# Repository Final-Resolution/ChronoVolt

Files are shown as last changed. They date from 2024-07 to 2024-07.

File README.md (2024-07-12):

# ChronoVolt

使用8-MD-06INKM制作的VFD时钟，基于ESP32-WROOM

## 项目概述

项目概述是关于项目的一段简短描述，解释该项目是什么以及它的目标和用途。

## 功能特点

列出项目的主要功能和特点，突出该项目的独特之处。

- 特点1：说明特点1的功能和优势。
- 特点2：说明特点2的功能和优势。
- 特点3：说明特点3的功能和优势。

## 安装和使用

提供项目的安装和使用指南，以帮助其他用户快速上手和开始使用该项目。

1. 安装步骤1。
2. 安装步骤2。
3. 使用示例代码或配置文件。

## 硬件设计

如果项目涉及硬件设计，可以提供有关硬件设计的详细信息。

- 原理图：放置原理图文件的链接或说明。
- 电路板布局：放置电路板布局文件的链接或说明。
- 元件清单：列出所使用的主要元件和器件。

## 软件/固件

如果项目涉及软件或固件开发，可以提供有关软件/固件的详细信息。

- 代码库：放置代码库的链接或说明。
- 依赖项：列出所需的主要软件或库的依赖项。

## 贡献

欢迎其他开发者和用户为该项目做出贡献。在贡献部分提供以下信息：

- 贡献方式：说明如何参与该项目的贡献，例如提交问题、提出建议或提交代码。 
- 贡献指南：提供贡献者应遵循的指南和行为准则。
- 开发环境设置：提供如何设置开发环境的说明。

## 许可证

在这个部分指定项目的许可证类型和版权信息。

## 联系方式

提供与项目相关的联系方式，例如邮件地址、社交媒体链接等。

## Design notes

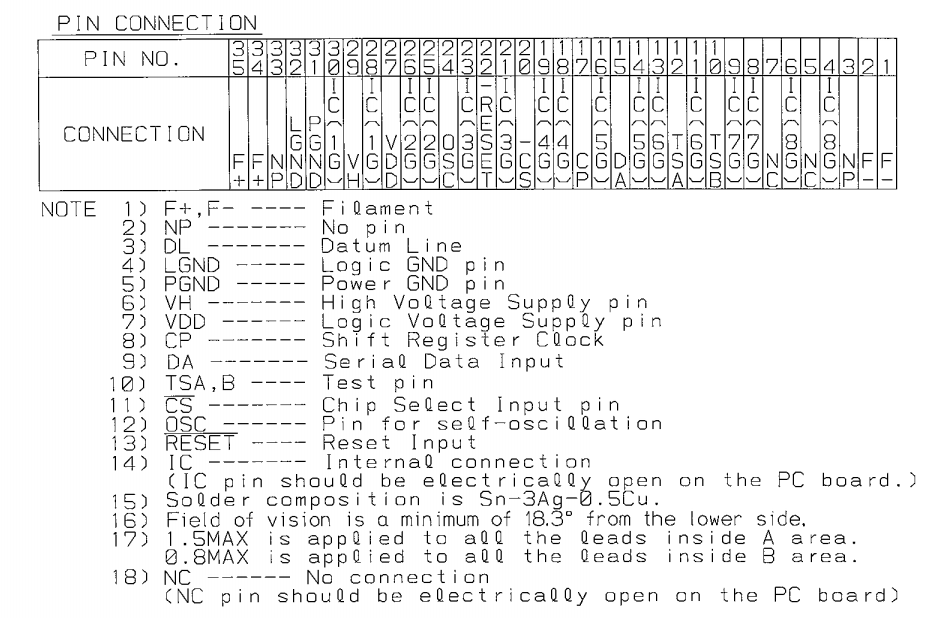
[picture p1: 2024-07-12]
1.Hardware/ChronoVolt_Control_Rev0.3/datasheets/8-MD-06INKM模块/8-MD-06INKM_PINOUT.png

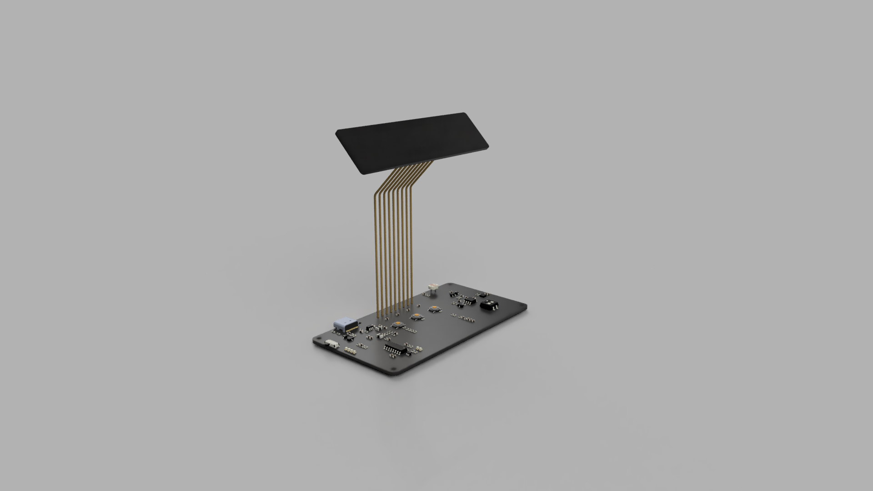
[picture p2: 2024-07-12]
4.Images/ChronoVolt_3D.PNG

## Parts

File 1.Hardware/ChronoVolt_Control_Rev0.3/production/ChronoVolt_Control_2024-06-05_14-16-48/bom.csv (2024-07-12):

Designator | Footprint | Quantity | Value | LCSC Part #
BT1 | CONN-SMD_ZH1.5-2P-WT | 1 | Battery
BT2 | BS-1220-2 | 1 | Battery_Cell
C1, C12, C2, C20, C21, C24, C25, C26, C27, C28, C29, C3, C30, C4, C9 | 0603 | 15 | 100nF
C10 | 0603 | 1 | 1uF
C11 | 0603 | 1 | 22uF
C13, C14 | 0603 | 2 | 9pF
C15, C32, C33 | 0603 | 3 | 0.1μF
C16, C17, C18, C19 | 0603 | 4 | 10uF
C5, C7, C8 | 0603 | 3 | 22μF
C6 | 0603 | 1 | 22pF
D10, D11, D12, D13 | LED-SMD_4P-L2.0-W1.8_CY-0807 | 4 | WS2812B
D14 | D_SOD-323 | 1 | 1N4148
D15, D16 | D_SOD-323 | 2 | 1N4148WS
D3 | 0603 | 1 | TX_LED
D4 | 0603 | 1 | RX_LED
D5 | D_SOD-323 | 1 | 1N5819
D6 | 0603 | 1 | 25%
D7 | 0603 | 1 | 50%
D8 | 0603 | 1 | 75%
D9 | 0603 | 1 | 100%
F1 | 0805 | 1 | Fuse
H1, H2, H3, H4 | MountingHole_2.5mm_Pad_Via | 4 | MountingHole_Pad
J1 | USB_C_Receptacle_Palconn_UTC16-G | 1 | USB_C_Receptacle_USB2.0
J2 | Con_Pin_1x09_3mm | 1 | Conn_01x09_Pin
L1 | 1008 | 1 | 2.2μH
L2 | 1008 | 1 | 1uH
LS1 | BUZ-SMD_4P-L8.5-W8.5-TL | 1 | Buzzer_MLT-8530_Passive
Q1 | TSOT-23 | 1 | CJ2301
Q3 | SOT-23 | 1 | AO3400A
R1, R2 | 0603 | 2 | 5.1K
R10, R11, R14, R15, R31, R36, R37, R38, R39, R40, R41, R7 | 0603 | 12 | 10K
R12, R13, R20, R21 | 0603 | 4 | 4.7K
R16 | 0603 | 1 | 4K7
R19, R24, R27, R32, R42 | 0603 | 5 | 0R
R23 | 0603 | 1 | 0.5R
R25, R26 | 0603 | 2 | 470K
R3, R33, R4, R5, R6 | 0603 | 5 | 470R
R30 | R_LDR_5.1x4.3mm_P3.4mm_Vertical | 1 | LDR_GL5528
R34 | 0603 | 1 | 100R
R35 | 0603 | 1 | 2K
R8 | 0603 | 1 | 100K
R9 | 0603 | 1 | 22K
SW1 | SW_SPDT_PCM12 | 1 | SW_Push_SPDT
SW2 | Panasonic_EVQPUL_EVQPUC | 1 | EN_KEY
SW3 | Panasonic_EVQPUL_EVQPUC | 1 | BOOT_KEY
SW5 | SW_SPST_TL3342 | 1 | UP_KEY
SW6 | SW_DIP_SPSTx02_Slide_6.7x6.64mm_W8.61mm_P2.54mm_LowProfile | 1 | MODE_SWITCH
SW7 | SW_SPST_TL3342 | 1 | ENTER_KEY
SW8 | SW_SPST_TL3342 | 1 | DOWN_KEY
TP1, TP3 | TestPoint_Pad_D1.0mm | 2 | TP_GND
TP2 | TestPoint_Pad_D1.0mm | 1 | TP_3V3
TP4 | TestPoint_Pad_D1.0mm | 1 | TP_VBUS
TP5 | TestPoint_Pad_D1.0mm | 1 | TP_+BATT
TP6 | TestPoint_Pad_D1.0mm | 1 | TP_BAT
TP7 | TestPoint_Pad_D1.0mm | 1 | TP_+5V
TP8 | TestPoint_Pad_D1.0mm | 1 | TP_+3v3
U1 | SOT-363_SC-70-6 | 1 | DDC114TU-7-F
U2 | SOIC-16_3.9x9.9mm_P1.27mm | 1 | CH340C
U3 | SOT-23-5 | 1 | SY8089AAAC
U4 | ESP32-WROOM-32D | 1 | ESP32-WROOM-32D
U5 | SOIC-8_3.9x4.9mm_P1.27mm | 1 | BM8563EMA
U6 | SOIC-8-1EP_3.9x4.9mm_P1.27mm_EP2.29x3mm_ThermalVias | 1 | IP5306
U8 | Sensirion_DFN-8-1EP_2.5x2.5mm_P0.5mm_EP1.1x1.7mm | 1 | SHT31-DIS
Y1 | Crystal_SMD_3215-2Pin_3.2x1.5mm | 1 | 32.768KHz

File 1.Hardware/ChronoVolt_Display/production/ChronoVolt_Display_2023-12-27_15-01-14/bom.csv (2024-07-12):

Designator | Footprint | Quantity | Value | LCSC Part #
C1 | 0603 | 1 | 0.1uF
C10, C3, C7, C9 | 0603 | 4 | 22μF
C2 | 0603 | 1 | 47uF
C4 | 0603 | 1 | 22pF/50V
C5 | 0603 | 1 | 0.1μF/50V
C6 | 0603 | 1 | 4.7μF/50V
C8 | 0603 | 1 | 22pF
D1, D2 | D_SOD-323 | 2 | 1N5819WS
J1 | Con_Pin_1x09_3mm | 1 | Conn_01x09_Pin
L1 | 1008 | 1 | 10uH
L2 | 1008 | 1 | 2.2μH
Q1 | TSOT-23 | 1 | CJ2301
R1, R2 | 0603 | 2 | 3R
R10, R13, R5, R6, R7 | 0603 | 5 | 10K
R11 | 0603 | 1 | 100K
R12 | 0603 | 1 | 22K
R3 | 0603 | 1 | 39K
R4 | 0603 | 1 | 180R
R8 | 0603 | 1 | 300K
R9 | 0603 | 1 | 16K
TP1 | TestPoint_Pad_D1.0mm | 1 | TP_GND
TP2 | TestPoint_Pad_D1.0mm | 1 | TP_+5V
TP3 | TestPoint_Pad_D1.0mm | 1 | TP_+3v3
TP4 | TestPoint_Pad_D1.0mm | 1 | TP_+24V
U1 | TSOT-23-5 | 1 | SGM6601YTN5G/TR
U2 | SOT-23-5 | 1 | SY8089AAAC
VFD1 | FUTABA_8-MD-06INKM | 1 | Futaba_8-MD-06INKM

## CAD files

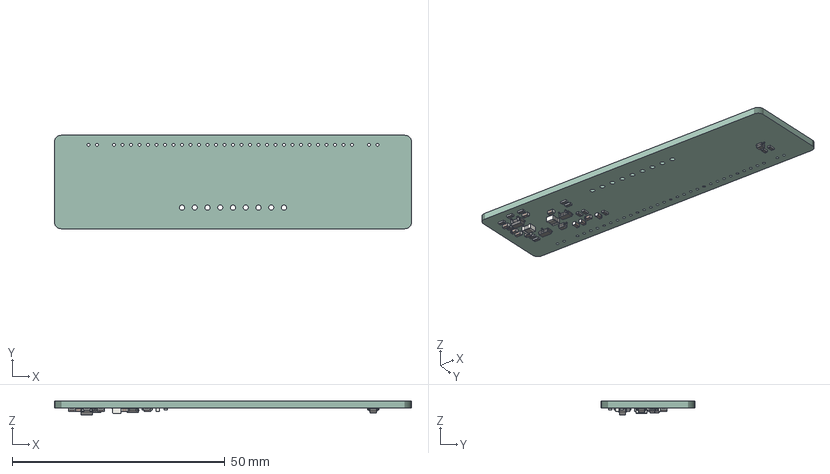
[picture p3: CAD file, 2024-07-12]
1.Hardware/ChronoVolt_Display/ChronoVolt_Display.step
84.0 x 22.0 x 3.20 mm
R_0603_1608Metric x 13
C_0603_1608Metric x 10
SOT_23_5
D_SOD_323 x 2
TSOT_23_5
L_1008_2520Metric x 2
TSOT_23
ChronoVolt_Display PCB

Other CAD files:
1.Hardware/ChronoVolt_Control_Rev0.3/datasheets/8-MD-06INKM模块/code/代码示例工程/test/output/main.obj
1.Hardware/ChronoVolt_Control_Rev0.3/datasheets/8-MD-06INKM模块/code/代码示例工程/test/output/common.obj
1.Hardware/ChronoVolt_Control_Rev0.3/datasheets/8-MD-06INKM模块/code/代码示例工程/test/output/clock.obj
1.Hardware/ChronoVolt_Control_Rev0.3/datasheets/8-MD-06INKM模块/code/代码示例工程/test/output/initial.obj
1.Hardware/ChronoVolt_Control_Rev0.3/datasheets/8-MD-06INKM模块/code/代码示例工程/test/output/sfr_macro.obj
1.Hardware/ChronoVolt_Control_Rev0.3/datasheets/8-MD-06INKM模块/code/代码示例工程/test/output/vfd_8md06inkm.obj
1.Hardware/ChronoVolt_Control_Rev0.3/datasheets/8-MD-06INKM模块/code/代码示例工程/test/output/pt6312.obj
1.Hardware/ChronoVolt_Control_Rev0.3/datasheets/8-MD-06INKM模块/code/代码示例工程/test/output/font_seg13.obj
1.Hardware/ChronoVolt_Control_Rev0.3/datasheets/8-MD-06INKM模块/code/代码示例工程/test/output/STARTUP.obj

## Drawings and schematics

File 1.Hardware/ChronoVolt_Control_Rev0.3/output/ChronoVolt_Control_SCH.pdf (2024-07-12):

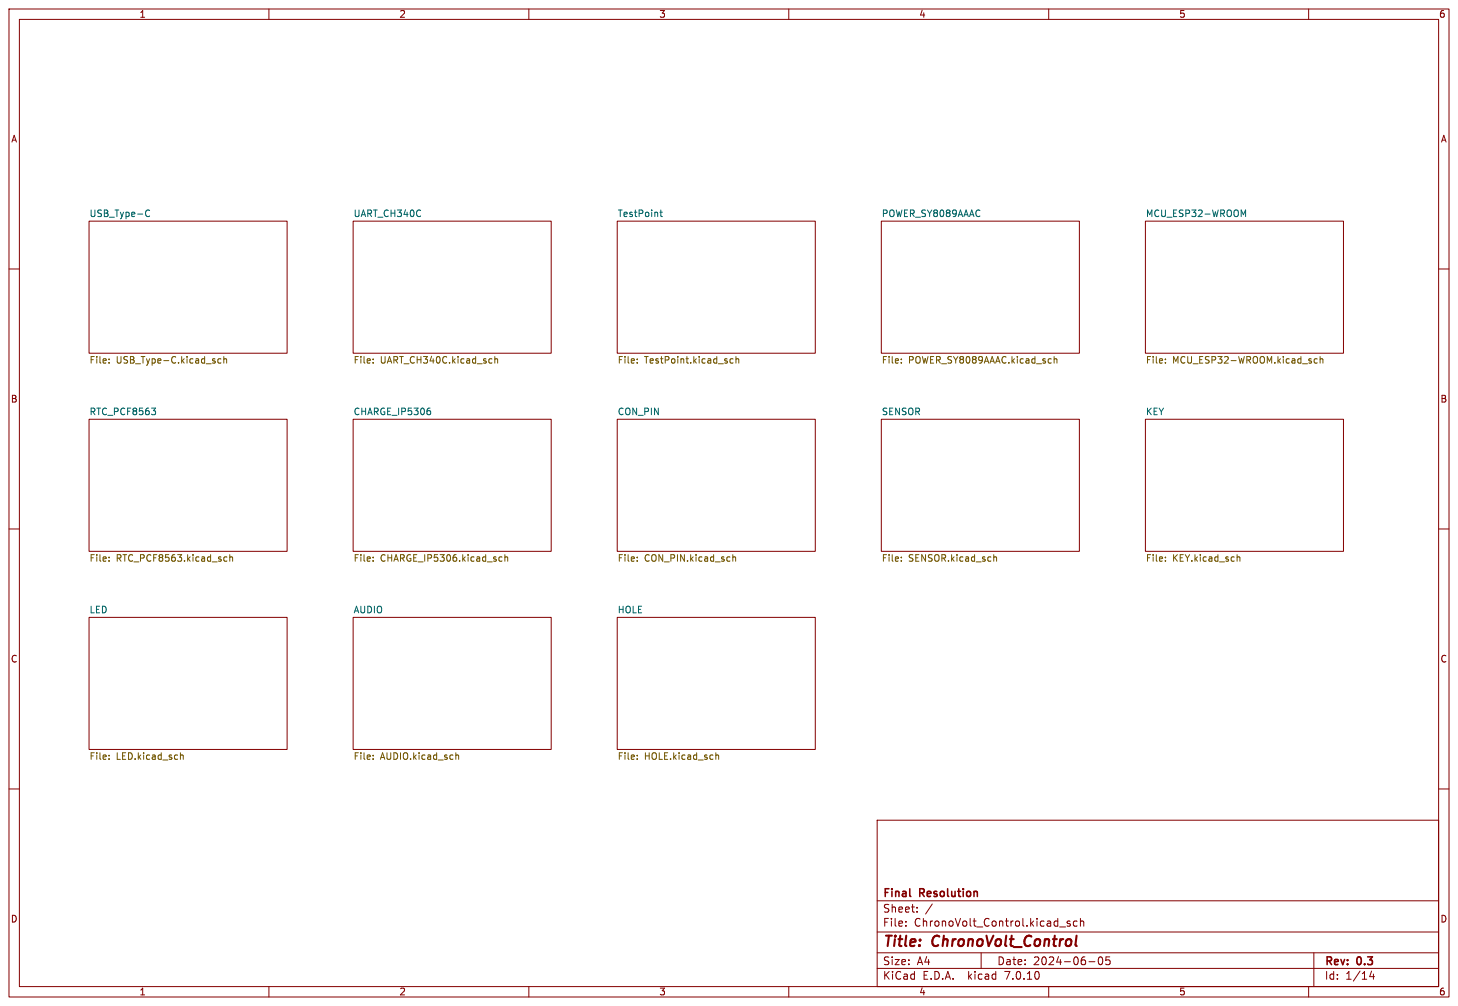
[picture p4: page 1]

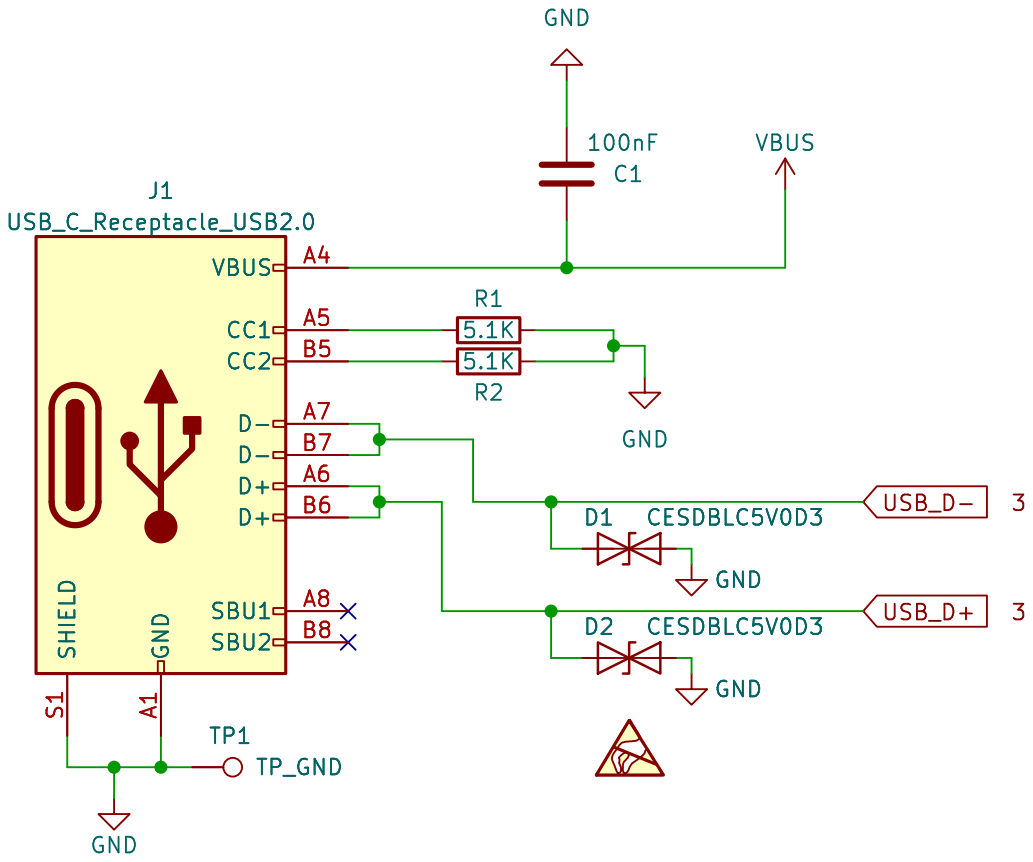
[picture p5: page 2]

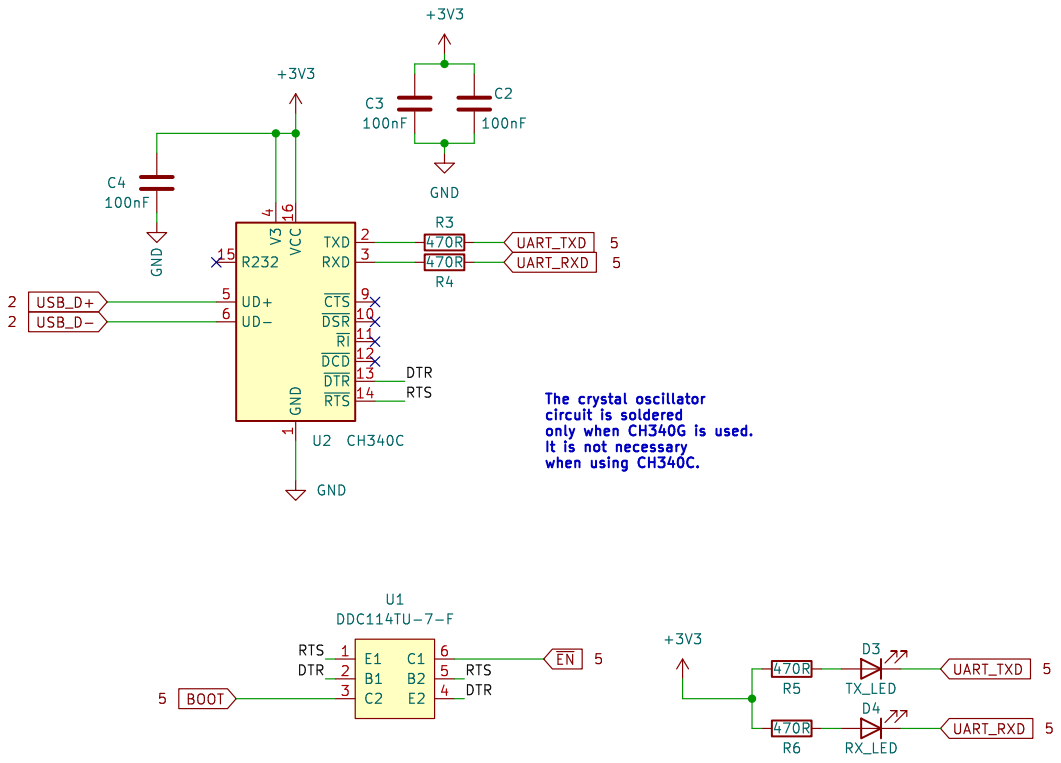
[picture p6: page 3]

1 ~{DSR} 10 ~{RI} 11 ~{DCD} 12 ~{DTR} 13 ~{RTS} 14 R232 15 VCC 16 TXD 2 RXD 3 V3

The crystal oscillator circuit is soldered

only when CH340G is used.
It is not necessary when using CH340C.

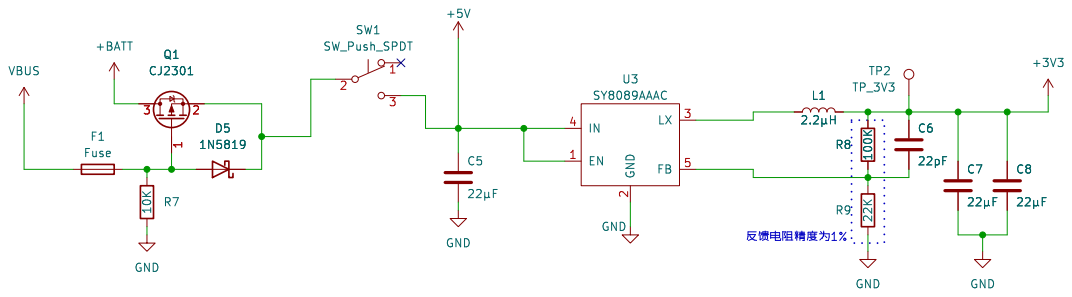
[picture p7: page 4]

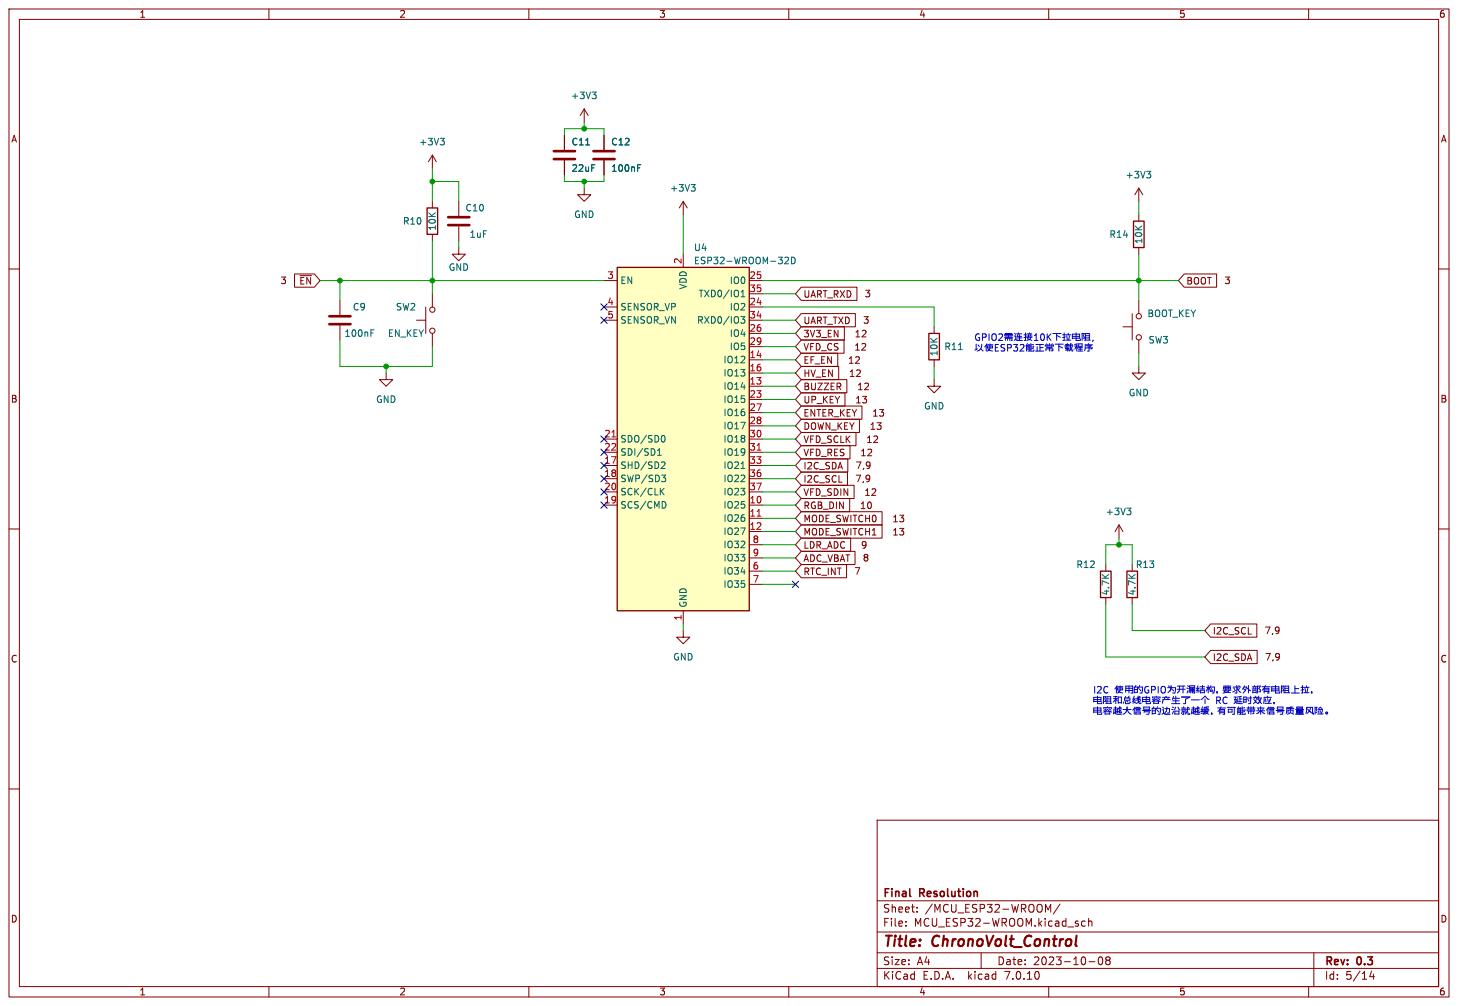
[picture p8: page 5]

2 SCK/CLK 20 SDO/SD0 21 SDI/SD1 22

I2C þÿO•u(v„GPION:_o~Óg„ÿ‰•lBY•èg u5–;N
þÿu5–;TŒ`;~¿u5[¹N§uN†NN*RC þÿ^öeöeH^”ÿ
þÿu5[¹•ŠY'OáS÷v„•¹l¿\1•Š•ÿg Sï€ý^&geOáS÷•(‘Ï˜Î–i0-

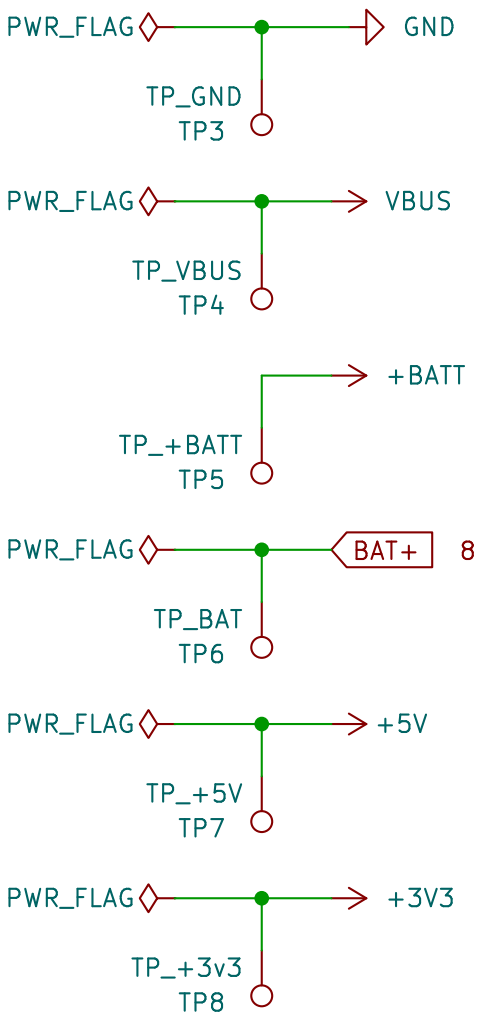
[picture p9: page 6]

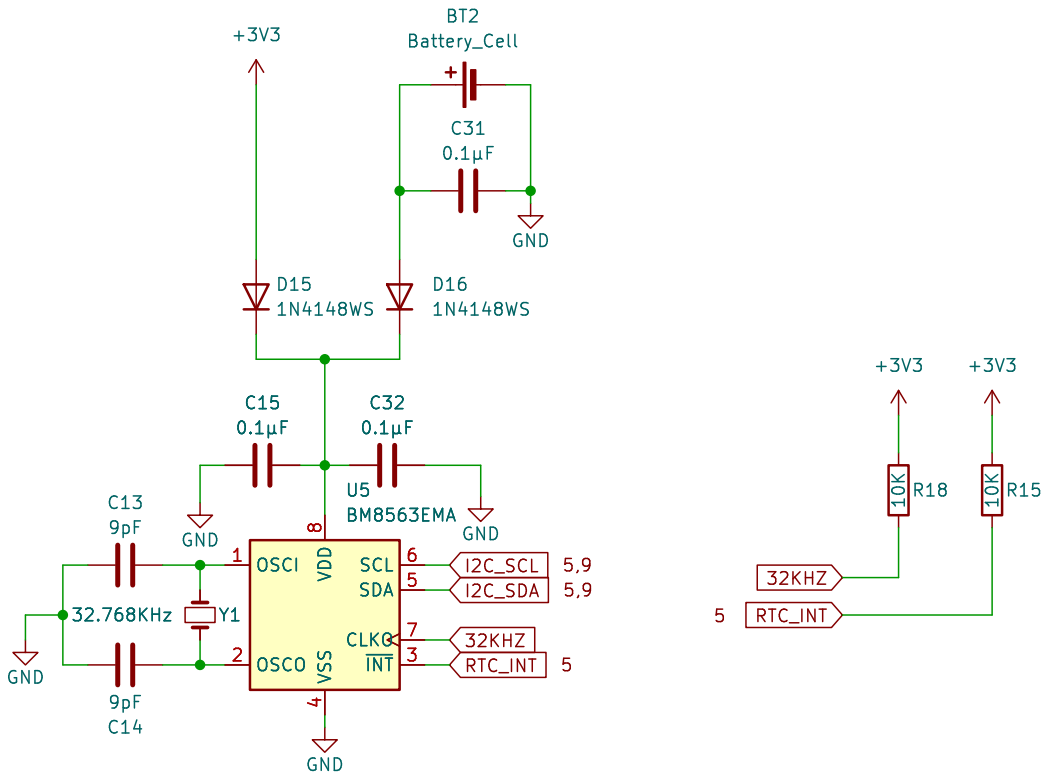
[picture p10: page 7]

4 SDA 5 SCL 6 CLKO 7 VDD

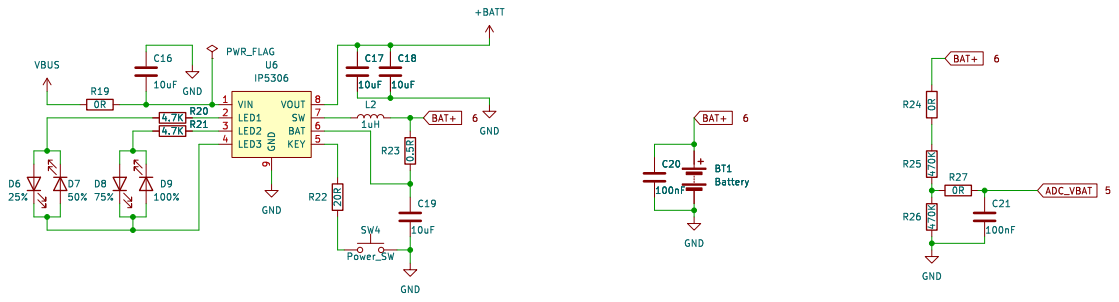
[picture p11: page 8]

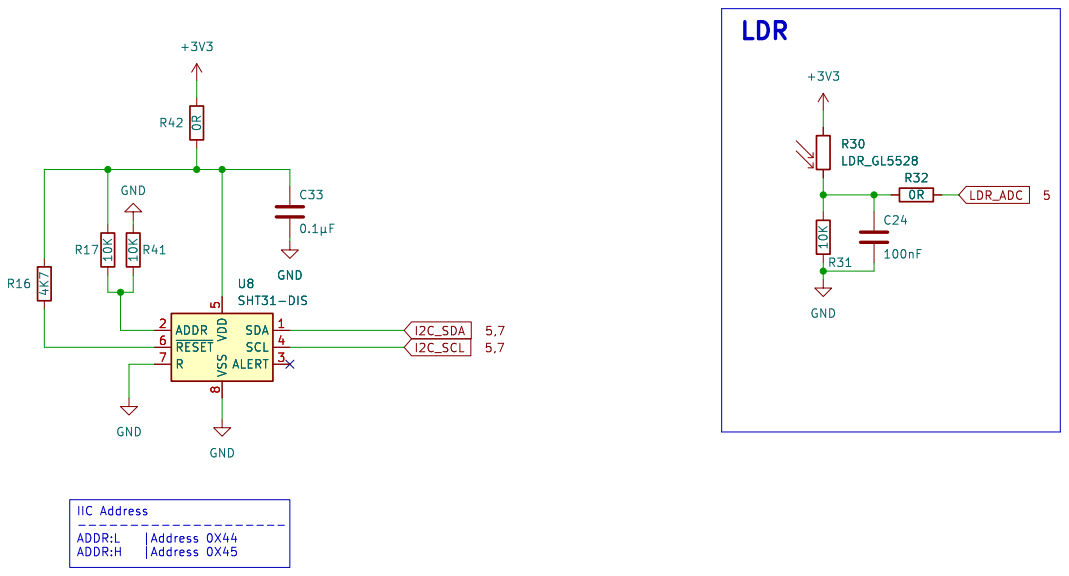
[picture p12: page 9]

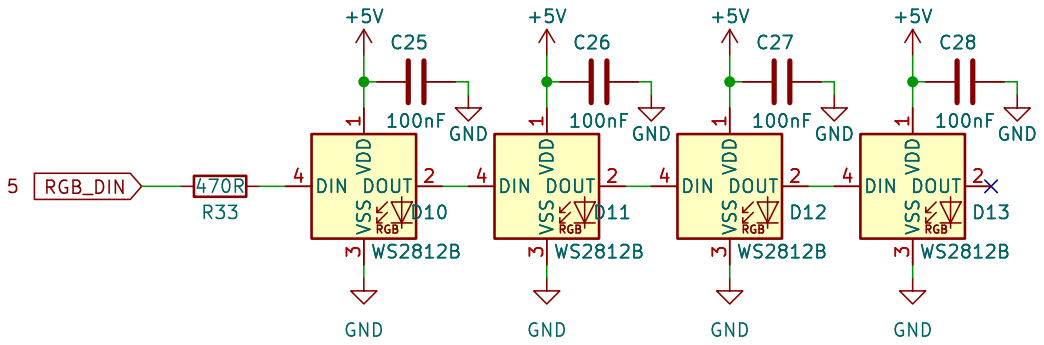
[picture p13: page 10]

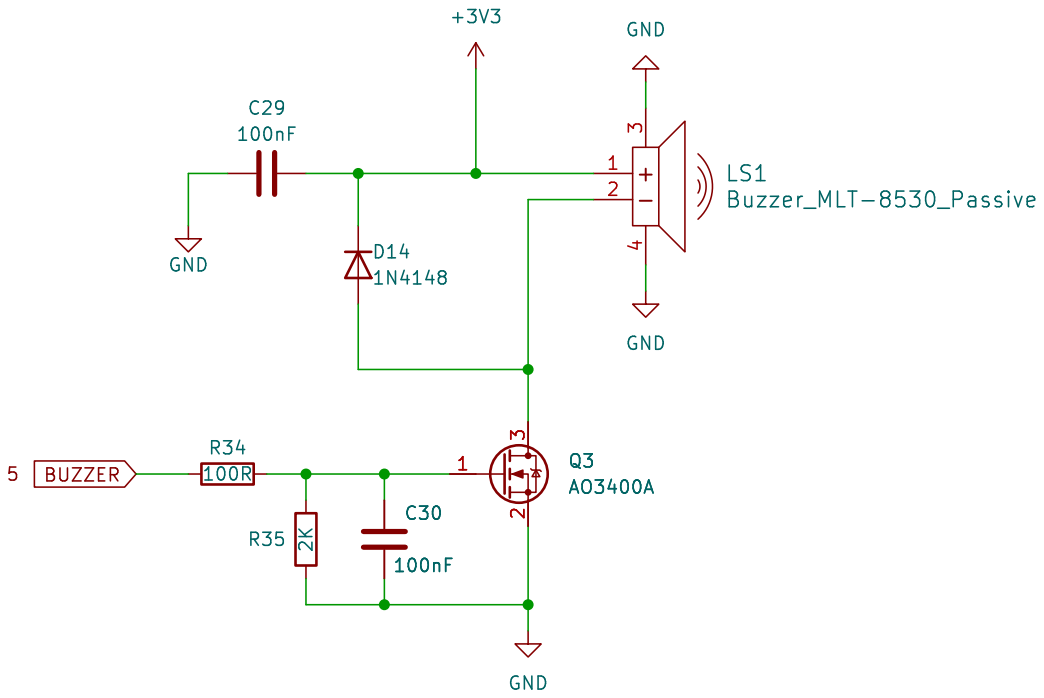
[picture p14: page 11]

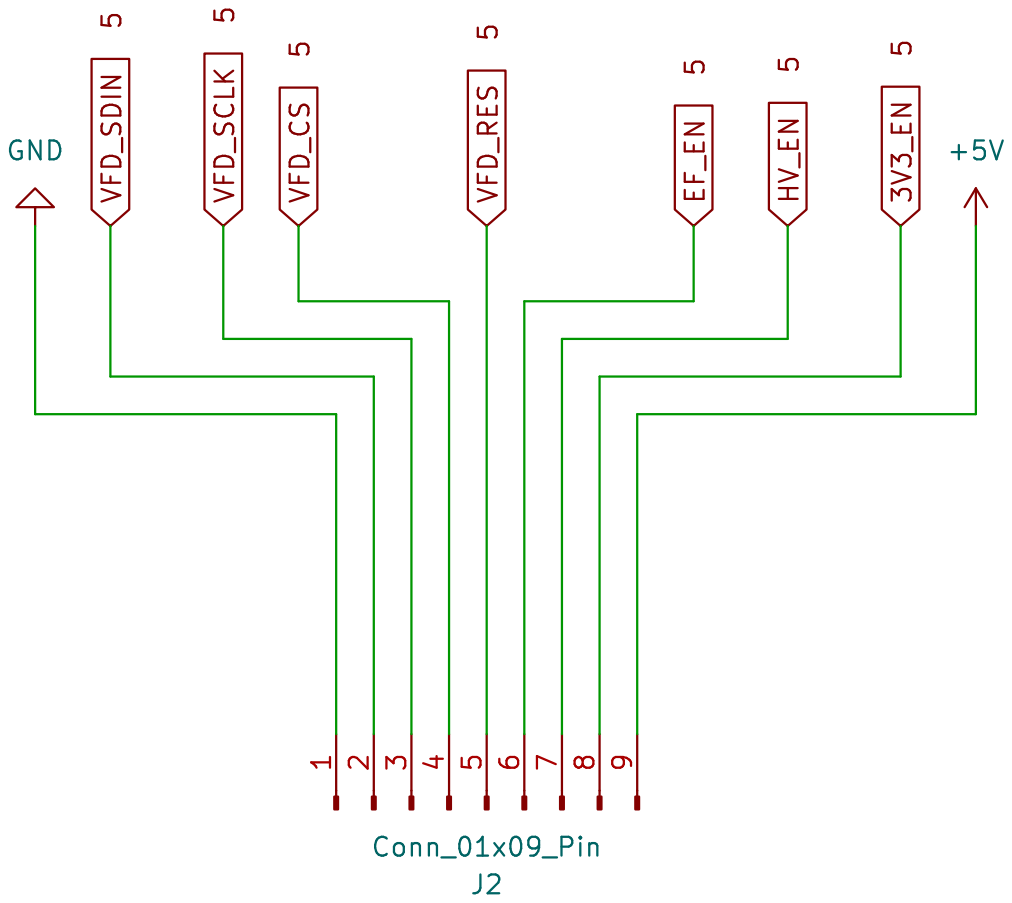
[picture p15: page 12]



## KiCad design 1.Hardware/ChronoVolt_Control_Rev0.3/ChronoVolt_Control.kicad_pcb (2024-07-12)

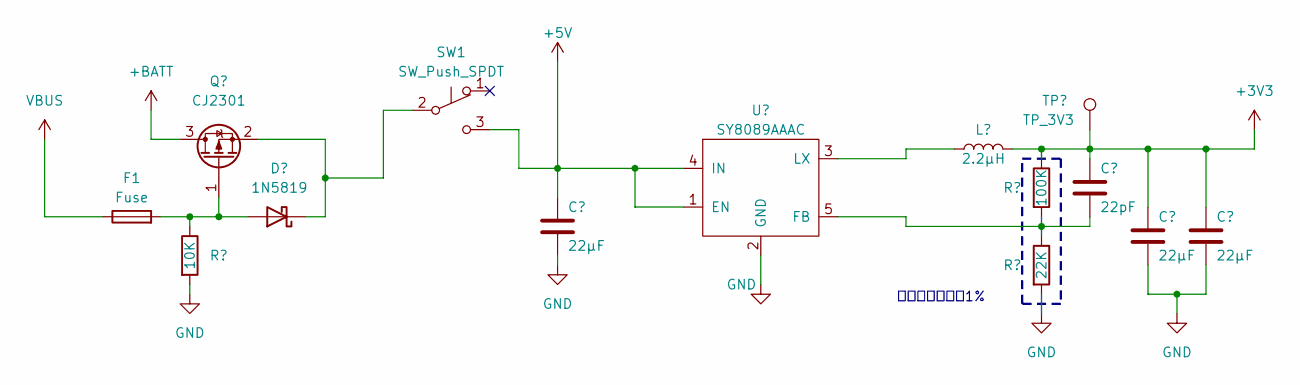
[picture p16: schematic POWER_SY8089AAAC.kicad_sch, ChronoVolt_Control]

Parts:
C5, C7, C8: 22μF; C_0603_1608Metric
C6: 22pF; C_0603_1608Metric
D5: 1N5819; D_SOD-323
F1: Fuse; Fuse_0805_2012Metric
L1: 2.2μH; L_1008_2520Metric
Q1: CJ2301; TSOT-23
R7: 10K; R_0603_1608Metric
R8: 100K; R_0603_1608Metric
R9: 22K; R_0603_1608Metric
SW1: SW_Push_SPDT; SW_SPDT_PCM12
TP2: TP_3V3; TestPoint_Pad_D1.0mm
U3: SY8089AAAC; SOT-23-5

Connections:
+3V3: C6.1, C7.1, C8.1, L1.2, R8.1, TP2.1; also elsewhere on the board
+5V: C5.1, SW1.3 (C), U3.1 (EN), U3.4 (IN); also elsewhere on the board
+BATT: Q1.3 (D); also elsewhere on the board
GND: C5.2, C7.2, C8.2, R7.2, R9.2, U3.2 (GND); also elsewhere on the board
unnamed: D5.2 (A), F1.2, Q1.1 (G), R7.1
unnamed: D5.1 (K), Q1.2 (S), SW1.2 (B)
unnamed: C6.2, R8.2, R9.1, U3.5 (FB)
unnamed: L1.1, U3.3 (LX)
VBUS: F1.1; also elsewhere on the board

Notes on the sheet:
反馈电阻精度为1%

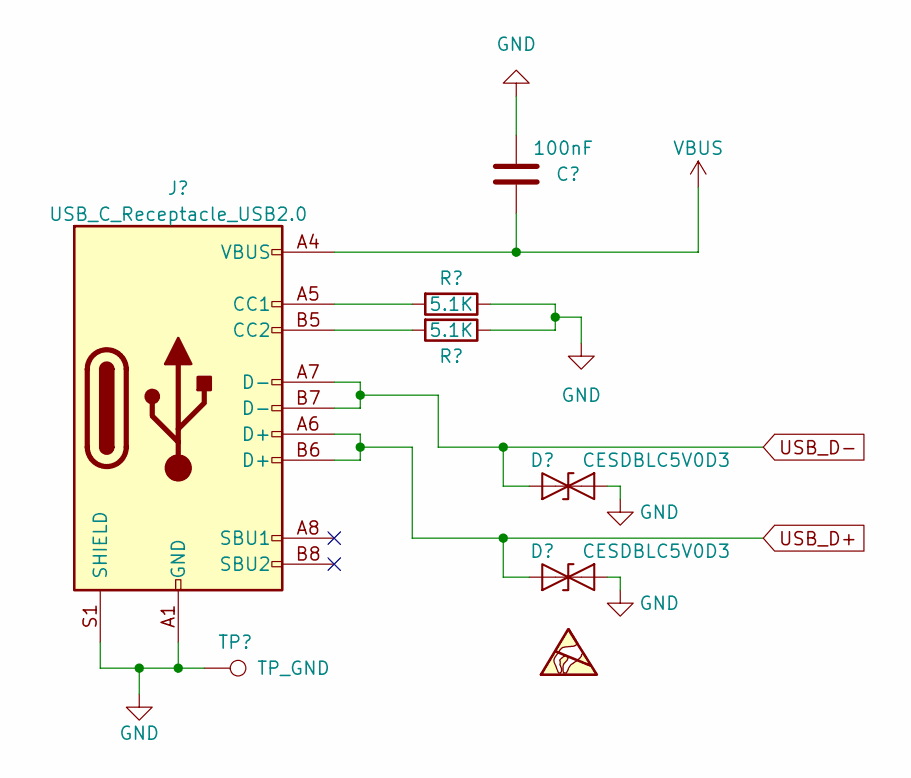
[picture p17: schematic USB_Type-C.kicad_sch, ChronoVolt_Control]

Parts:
C1: 100nF; C_0603_1608Metric
D1, D2: CESDBLC5V0D3; D_SOD-923
J1: USB_C_Receptacle_USB2.0; USB_C_Receptacle_Palconn_UTC16-G
R1, R2: 5.1K; R_0603_1608Metric
TP1: TP_GND; TestPoint_Pad_D1.0mm

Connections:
GND: C1.2, D1.1 (A1), D2.1 (A1), J1.A1 (GND), J1.A12 (GND), J1.B1 (GND), J1.B12 (GND), J1.S1 (SHIELD), R1.1, R2.1, TP1.1; also elsewhere on the board
unnamed: J1.A5 (CC1), R1.2
unnamed: J1.B5 (CC2), R2.2
USB_D+: D2.2 (A2), J1.A6 (D+), J1.B6 (D+); also elsewhere on the board
USB_D-: D1.2 (A2), J1.A7 (D-), J1.B7 (D-); also elsewhere on the board
VBUS: C1.1, J1.A4 (VBUS), J1.A9 (VBUS), J1.B4 (VBUS), J1.B9 (VBUS); also elsewhere on the board

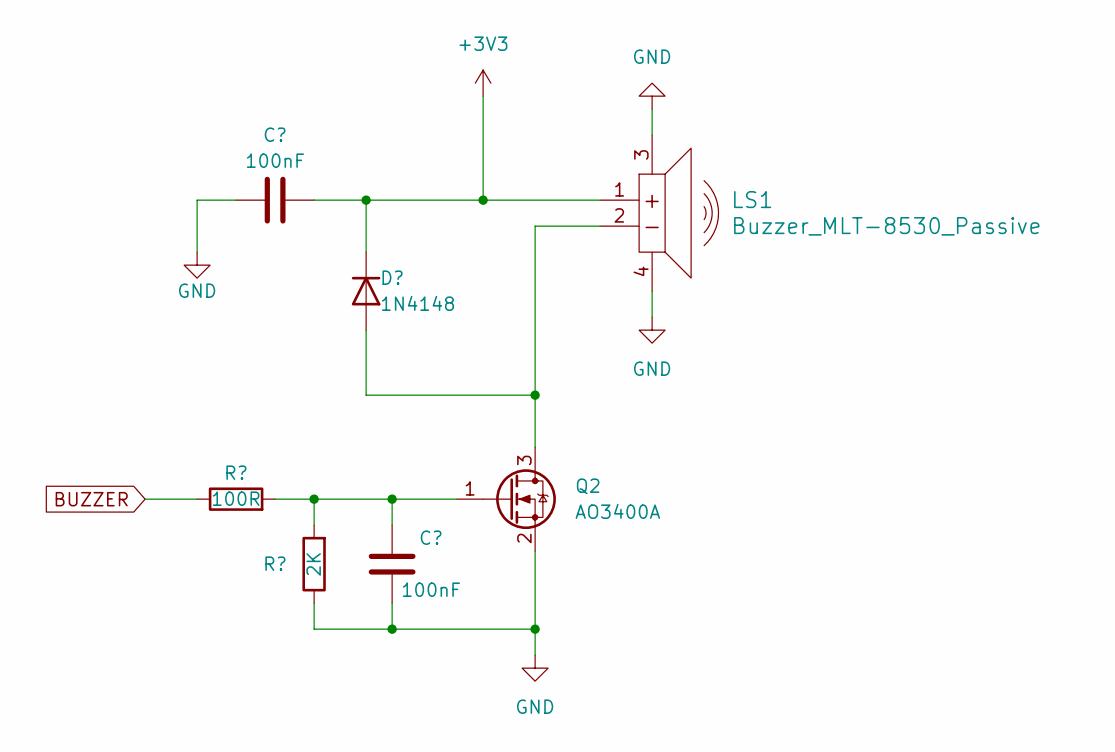
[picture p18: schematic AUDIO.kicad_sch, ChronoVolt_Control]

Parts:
C29, C30: 100nF; C_0603_1608Metric
D14: 1N4148; D_SOD-323
LS1: Buzzer_MLT-8530_Passive; BUZ-SMD_4P-L8.5-W8.5-TL
Q2: AO3400A; SOT-23
R34: 100R; R_0603_1608Metric
R35: 2K; R_0603_1608Metric

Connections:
+3V3: C29.2, D14.1 (K), LS1.1; also elsewhere on the board
BUZZER: R34.1; also elsewhere on the board
GND: C29.1, C30.2, LS1.3, LS1.4, R35.1; also elsewhere on the board
unnamed 34: D14.2 (A), LS1.2; also elsewhere on the board
unnamed 38: C30.1, R34.2, R35.2; also elsewhere on the board

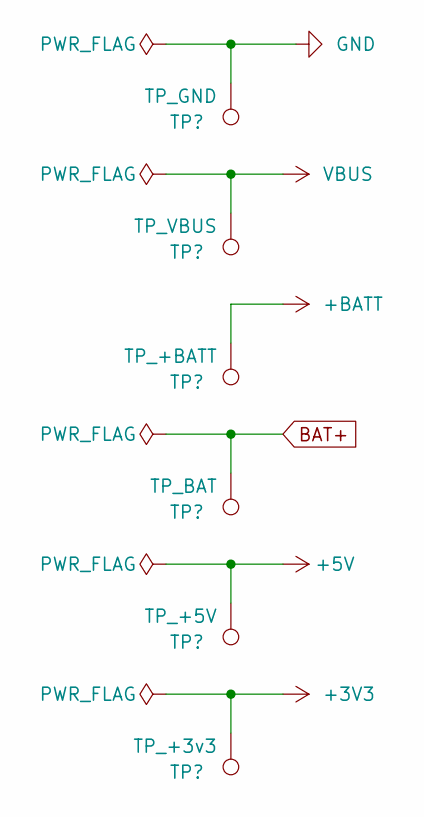
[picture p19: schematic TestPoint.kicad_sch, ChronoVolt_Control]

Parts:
TP3: TP_GND; TestPoint_Pad_D1.0mm
TP4: TP_VBUS; TestPoint_Pad_D1.0mm
TP5: TP_+BATT; TestPoint_Pad_D1.0mm
TP6: TP_BAT; TestPoint_Pad_D1.0mm
TP7: TP_+5V; TestPoint_Pad_D1.0mm
TP8: TP_+3v3; TestPoint_Pad_D1.0mm

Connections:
+3V3: TP8.1; also elsewhere on the board
+5V: TP7.1; also elsewhere on the board
+BATT: TP5.1; also elsewhere on the board
BAT+: TP6.1; also elsewhere on the board
GND: TP3.1; also elsewhere on the board
VBUS: TP4.1; also elsewhere on the board

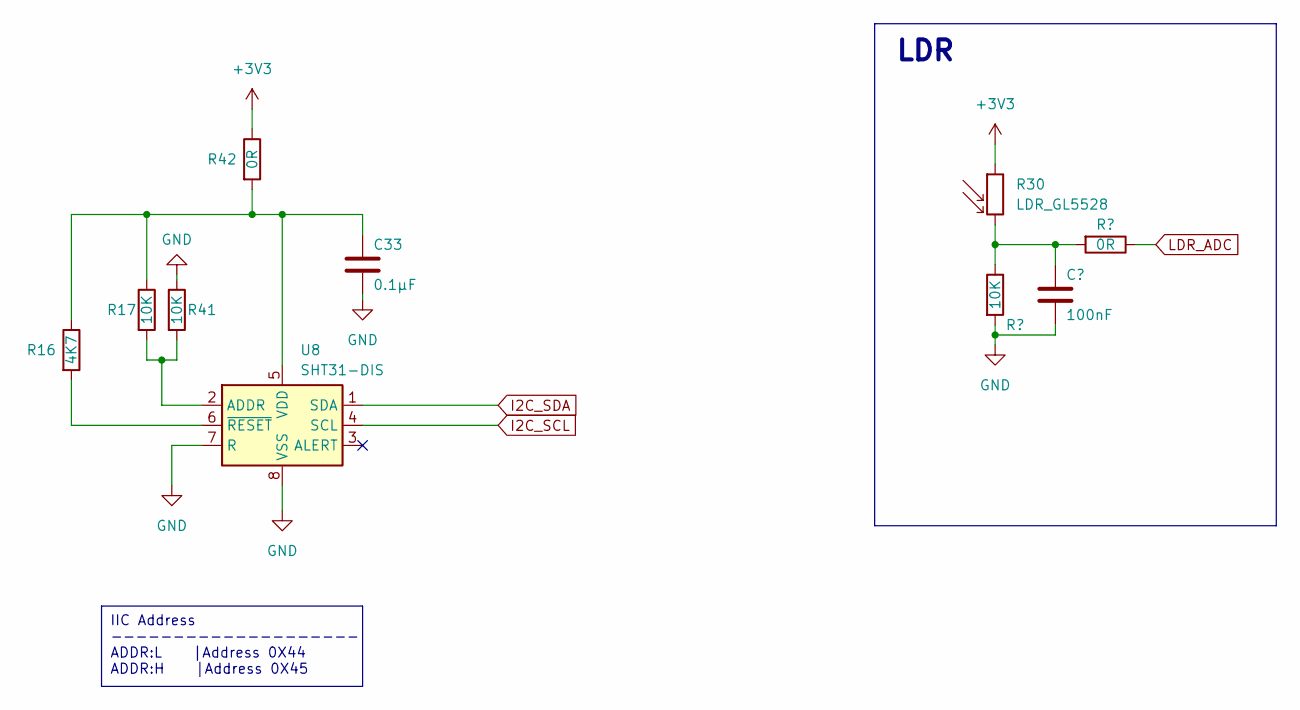
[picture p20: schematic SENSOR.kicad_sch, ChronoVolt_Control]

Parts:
C24: 100nF; C_0603_1608Metric
C33: 0.1μF; C_0603_1608Metric
R16: 4K7; R_0603_1608Metric
R17, R31, R41: 10K; R_0603_1608Metric
R30: LDR_GL5528; R_LDR_5.1x4.3mm_P3.4mm_Vertical
R32, R42: 0R; R_0603_1608Metric
U8: SHT31-DIS; Sensirion_DFN-8-1EP_2.5x2.5mm_P0.5mm_EP1.1x1.7mm

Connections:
+3V3: R30.1, R42.1; also elsewhere on the board
GND: C24.2, C33.2, R31.2, R41.1, U8.7 (R), U8.8 (VSS), U8.9 (VSS); also elsewhere on the board
I2C_SCL: U8.4 (SCL); also elsewhere on the board
I2C_SDA: U8.1 (SDA); also elsewhere on the board
LDR_ADC: R32.1; also elsewhere on the board
unnamed: C24.1, R30.2, R31.1, R32.2
unnamed: R17.2, R41.2, U8.2 (ADDR)
unnamed: C33.1, R16.1, R17.1, R42.2, U8.5 (VDD)
unnamed: R16.2, U8.6 (~RESET)

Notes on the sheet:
IIC Address -------------------- ADDR:L |Address 0X44 ADDR:H |Address 0X45
LDR

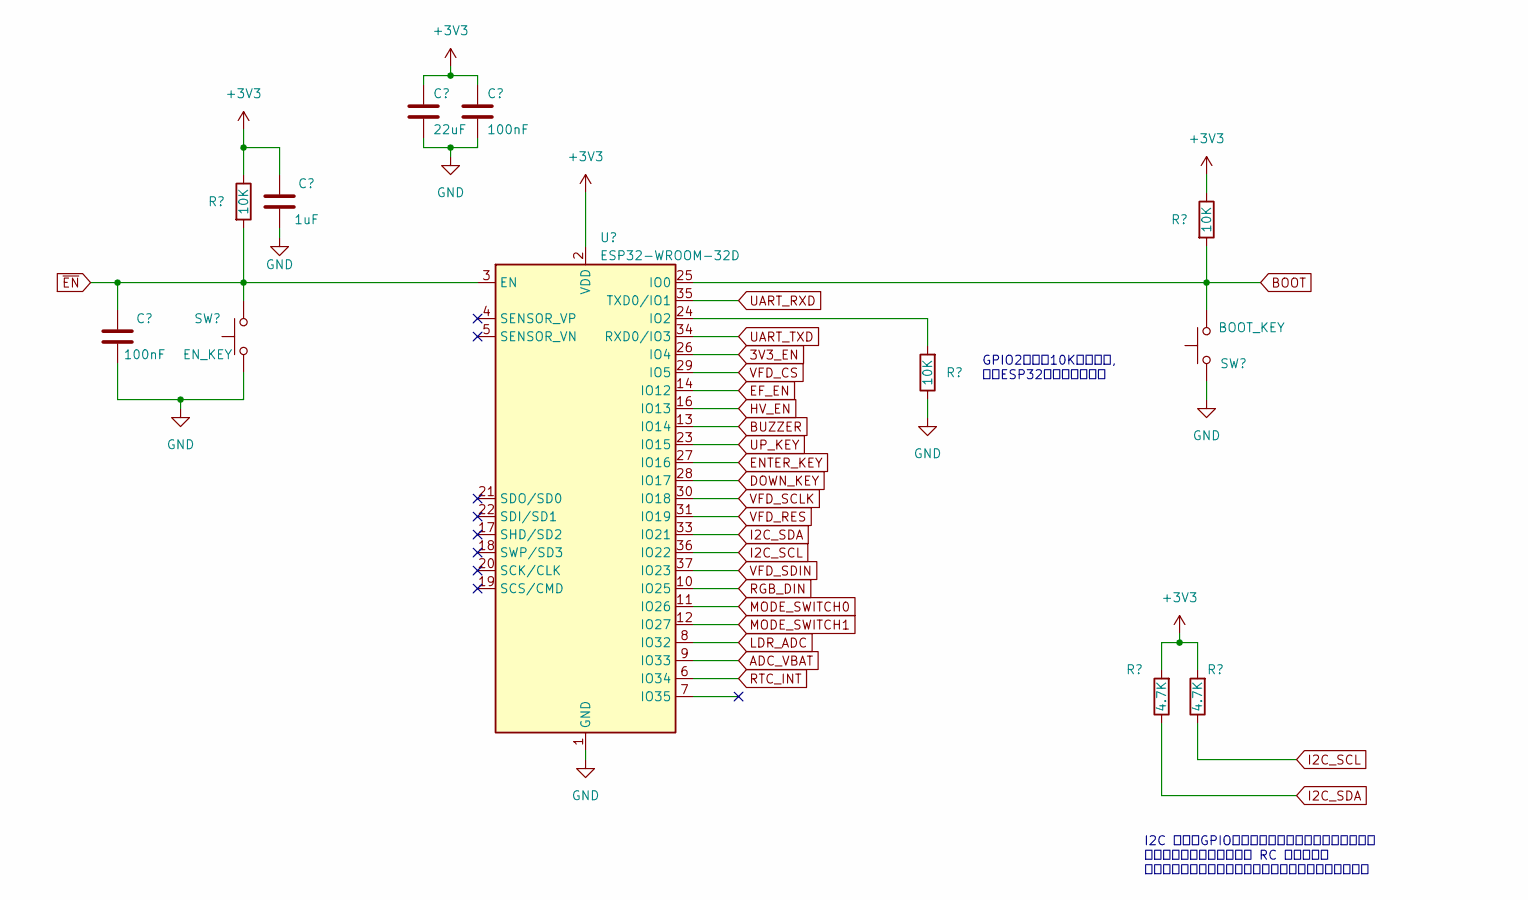
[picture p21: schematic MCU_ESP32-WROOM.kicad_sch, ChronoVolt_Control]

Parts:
C9, C12: 100nF; C_0603_1608Metric
C10: 1uF; C_0603_1608Metric
C11: 22uF; C_0603_1608Metric
R10, R11, R14: 10K; R_0603_1608Metric
R12, R13: 4.7K; R_0603_1608Metric
SW2: EN_KEY; Panasonic_EVQPUL_EVQPUC
SW3: BOOT_KEY; Panasonic_EVQPUL_EVQPUC
U4: ESP32-WROOM-32D

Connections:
3V3_EN: U4.26 (IO4); also elsewhere on the board
+3V3: C10.2, C11.1, C12.1, R10.1, R12.2, R13.2, R14.1, U4.2 (VDD); also elsewhere on the board
ADC_VBAT: U4.9 (IO33); also elsewhere on the board
BOOT: R14.2, SW3.2, U4.25 (IO0); also elsewhere on the board
BUZZER: U4.13 (IO14); also elsewhere on the board
DOWN_KEY: U4.28 (IO17); also elsewhere on the board
EF_EN: U4.14 (IO12); also elsewhere on the board
ENTER_KEY: U4.27 (IO16); also elsewhere on the board
GND: C9.1, C10.1, C11.2, C12.2, R11.1, SW2.1, SW3.1, U4.1 (GND), U4.15 (GND), U4.38 (GND), U4.39 (GND); also elsewhere on the board
HV_EN: U4.16 (IO13); also elsewhere on the board
I2C_SCL: R13.1, U4.36 (IO22); also elsewhere on the board
I2C_SDA: R12.1, U4.33 (IO21); also elsewhere on the board
LDR_ADC: U4.8 (IO32); also elsewhere on the board
MODE_SWITCH0: U4.11 (IO26); also elsewhere on the board
MODE_SWITCH1: U4.12 (IO27); also elsewhere on the board
unnamed: R11.2, U4.24 (IO2)
RGB_DIN: U4.10 (IO25); also elsewhere on the board
RTC_INT: U4.6 (IO34); also elsewhere on the board
UART_RXD: U4.35 (TXD0/IO1); also elsewhere on the board
UART_TXD: U4.34 (RXD0/IO3); also elsewhere on the board
UP_KEY: U4.23 (IO15); also elsewhere on the board
VFD_CS: U4.29 (IO5); also elsewhere on the board
VFD_RES: U4.31 (IO19); also elsewhere on the board
VFD_SCLK: U4.30 (IO18); also elsewhere on the board
VFD_SDIN: U4.37 (IO23); also elsewhere on the board
~EN: C9.2, R10.2, SW2.2, U4.3 (EN); also elsewhere on the board

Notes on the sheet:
I2C 使用的GPIO为开漏结构，要求外部有电阻上拉， 电阻和总线电容产生了一个 RC 延时效应， 电容越大信号的边沿就越缓，有可能带来信号质量风险。
GPIO2需连接10K下拉电阻, 以使ESP32能正常下载程序

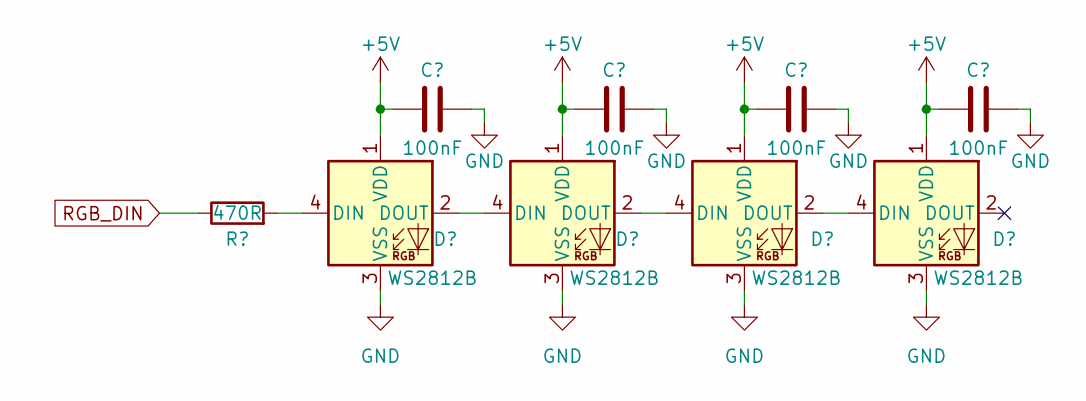
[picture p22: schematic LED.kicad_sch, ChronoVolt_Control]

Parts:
C25, C26, C27, C28: 100nF; C_0603_1608Metric
D10, D11, D12, D13: WS2812B; LED-SMD_4P-L2.0-W1.8_CY-0807
R33: 470R; R_0603_1608Metric

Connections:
+5V: C25.1, C26.1, C27.1, C28.1, D10.1 (VDD), D11.1 (VDD), D12.1 (VDD), D13.1 (VDD); also elsewhere on the board
GND: C25.2, C26.2, C27.2, C28.2, D10.3 (VSS), D11.3 (VSS), D12.3 (VSS), D13.3 (VSS); also elsewhere on the board
unnamed: D10.4 (DIN), R33.2
unnamed: D10.2 (DOUT), D11.4 (DIN)
unnamed: D11.2 (DOUT), D12.4 (DIN)
unnamed: D12.2 (DOUT), D13.4 (DIN)
RGB_DIN: R33.1; also elsewhere on the board

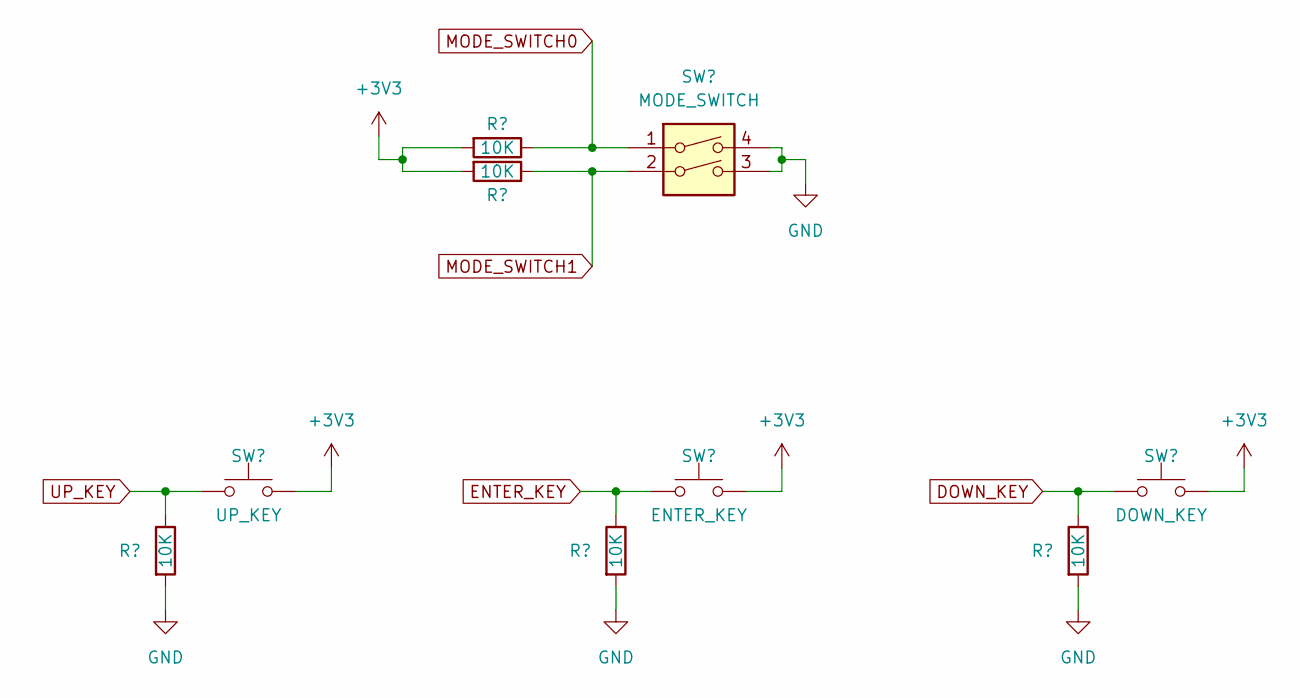
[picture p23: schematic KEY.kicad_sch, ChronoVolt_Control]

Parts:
R36, R37, R38, R39, R40: 10K; R_0603_1608Metric
SW5: UP_KEY; SW_SPST_TL3342
SW6: MODE_SWITCH; SW_DIP_SPSTx02_Slide_6.7x6.64mm_W8.61mm_P2.54mm_LowProfile
SW7: ENTER_KEY; SW_SPST_TL3342
SW8: DOWN_KEY; SW_SPST_TL3342

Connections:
+3V3: R37.2, R38.2, SW5.2, SW7.2, SW8.2; also elsewhere on the board
DOWN_KEY: R40.1, SW8.1; also elsewhere on the board
ENTER_KEY: R39.1, SW7.1; also elsewhere on the board
GND: R36.2, R39.2, R40.2, SW6.3, SW6.4; also elsewhere on the board
MODE_SWITCH0: R37.1, SW6.1; also elsewhere on the board
MODE_SWITCH1: R38.1, SW6.2; also elsewhere on the board
UP_KEY: R36.1, SW5.1; also elsewhere on the board

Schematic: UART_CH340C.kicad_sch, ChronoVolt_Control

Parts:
C2, C3, C4: 100nF; C_0603_1608Metric
D3: TX_LED; LED_0603_1608Metric
D4: RX_LED; LED_0603_1608Metric
R3, R4, R5, R6: 470R; R_0603_1608Metric
U1: DDC114TU-7-F; SOT-363_SC-70-6
U2: CH340C; SOIC-16_3.9x9.9mm_P1.27mm

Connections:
+3V3: C2.2, C3.2, C4.2, R5.1, R6.1, U2.4 (V3), U2.16 (VCC); also elsewhere on the board
/UART_CH340C/DTR: U1.2 (B1), U1.4 (E2), U2.13 (~DTR)
/UART_CH340C/RTS: U1.1 (E1), U1.5 (B2), U2.14 (~RTS)
BOOT: U1.3 (C2); also elsewhere on the board
GND: C2.1, C3.1, C4.1, U2.1 (GND); also elsewhere on the board
unnamed: D3.2 (A), R5.2
unnamed: D4.2 (A), R6.2
unnamed: R4.1, U2.3 (RXD)
unnamed: R3.1, U2.2 (TXD)
UART_RXD: D4.1 (K), R4.2; also elsewhere on the board
UART_TXD: D3.1 (K), R3.2; also elsewhere on the board
USB_D+: U2.5 (UD+); also elsewhere on the board
USB_D-: U2.6 (UD-); also elsewhere on the board
~EN: U1.6 (C1); also elsewhere on the board

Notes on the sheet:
The crystal oscillator circuit is soldered only when CH340G is used. It is not necessary when using CH340C.

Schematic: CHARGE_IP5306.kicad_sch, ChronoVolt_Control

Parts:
BT1: Battery; CONN-SMD_ZH1.5-2P-WT
C16, C17, C18, C19: 10uF; C_0603_1608Metric
C20, C21: 100nF; C_0603_1608Metric
D6: 25%; LED_0603_1608Metric
D7: 50%; LED_0603_1608Metric
D8: 75%; LED_0603_1608Metric
D9: 100%; LED_0603_1608Metric
L2: 1uH; L_1008_2520Metric
R19, R24, R27: 0R; R_0603_1608Metric
R20, R21: 4.7K; R_0603_1608Metric
R22: 20R; R_0603_1608Metric
R23: 0.5R; R_0603_1608Metric
R25, R26: 470K; R_0603_1608Metric
SW4: Power_SW; Panasonic_EVQPUL_EVQPUC
U6: IP5306; SOIC-8-1EP_3.9x4.9mm_P1.27mm_EP2.29x3mm_ThermalVias

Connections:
+BATT: C17.1, C18.1, U6.8 (VOUT); also elsewhere on the board
ADC_VBAT: C21.1, R27.1; also elsewhere on the board
BAT+: BT1.1 (+), C20.1, L2.2, R23.2, R24.2; also elsewhere on the board
GND: BT1.2 (-), C16.1, C17.2, C18.2, C19.2, C20.2, C21.2, R26.1, SW4.2, U6.9 (GND); also elsewhere on the board
unnamed: D6.2 (A), D7.1 (K), R20.1
unnamed: D6.1 (K), D7.2 (A), D8.1 (K), D9.2 (A), U6.4 (LED3)
unnamed: D8.2 (A), D9.1 (K), R21.1
unnamed: R22.1, SW4.1
unnamed: R24.1, R25.2
unnamed: R25.1, R26.2, R27.2
unnamed: C19.1, R23.1, U6.6 (BAT)
unnamed: R22.2, U6.5 (KEY)
unnamed: R20.2, U6.2 (LED1)
unnamed: R21.2, U6.3 (LED2)
unnamed: L2.1, U6.7 (SW)
unnamed: C16.2, R19.2, U6.1 (VIN)
VBUS: R19.1; also elsewhere on the board

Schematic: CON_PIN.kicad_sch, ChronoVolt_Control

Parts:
J2: Conn_01x09_Pin; Con_Pin_1x09_3mm

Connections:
3V3_EN: J2.8; also elsewhere on the board
+5V: J2.9; also elsewhere on the board
EF_EN: J2.6; also elsewhere on the board
GND: J2.1; also elsewhere on the board
HV_EN: J2.7; also elsewhere on the board
VFD_CS: J2.4; also elsewhere on the board
VFD_RES: J2.5; also elsewhere on the board
VFD_SCLK: J2.3; also elsewhere on the board
VFD_SDIN: J2.2; also elsewhere on the board

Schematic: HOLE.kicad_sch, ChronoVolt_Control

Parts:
H1, H2, H3, H4: MountingHole_Pad; MountingHole_2.5mm_Pad_Via

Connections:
GND: H1.1, H2.1, H3.1, H4.1; also elsewhere on the board

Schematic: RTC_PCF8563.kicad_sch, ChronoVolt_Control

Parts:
BT2: Battery_Cell; BS-1220-2
C13, C14: 9pF; C_0603_1608Metric
C15, C31, C32: 0.1μF; C_0603_1608Metric
D15, D16: 1N4148WS; D_SOD-323
R15, R18: 10K; R_0603_1608Metric
U5: BM8563EMA; SOIC-8_3.9x4.9mm_P1.27mm
Y1: 32.768KHz; Crystal_SMD_3215-2Pin_3.2x1.5mm

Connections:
32KHZ: R18.2, U5.7 (CLKO)
+3V3: D15.2 (A), R15.1, R18.1; also elsewhere on the board
GND: BT2.2 (-), C13.1, C14.1, C15.1, C31.2, C32.2, U5.4 (VSS); also elsewhere on the board
I2C_SCL: U5.6 (SCL); also elsewhere on the board
I2C_SDA: U5.5 (SDA); also elsewhere on the board
unnamed: BT2.1 (+), C31.1, D16.2 (A)
unnamed: C15.2, C32.1, D15.1 (K), D16.1 (K), U5.8 (VDD)
unnamed: C13.2, U5.1 (OSCI), Y1.1
unnamed: C14.2, U5.2 (OSCO), Y1.2
RTC_INT: R15.2, U5.3 (~INT); also elsewhere on the board

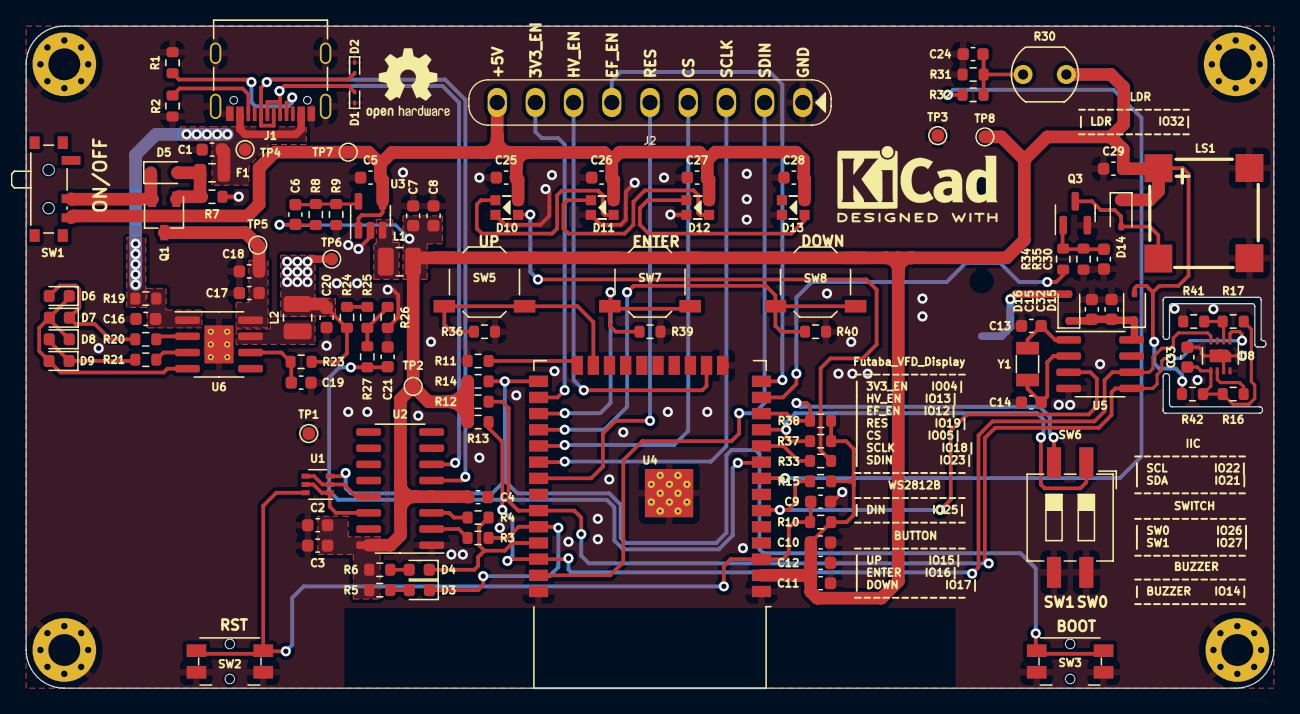
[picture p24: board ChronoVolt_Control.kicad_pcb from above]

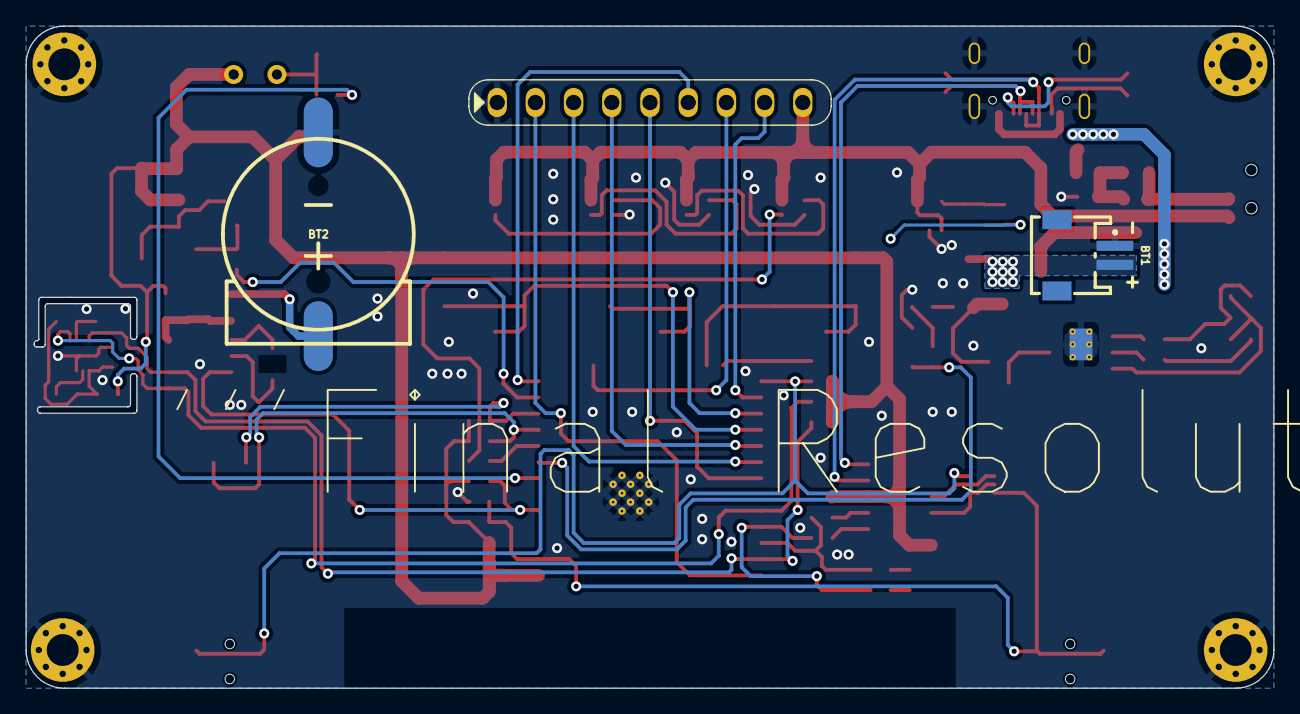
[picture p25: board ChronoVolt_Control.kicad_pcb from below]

Board: 2 copper layers, 98.0 x 52.0 mm, 121 parts (2 on the bottom side), 68 nets.

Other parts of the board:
Q3: AO3400A; SOT-23

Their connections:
GND: Q3.2 (S); also elsewhere on the board
unnamed 34: Q3.3 (D); also elsewhere on the board
unnamed 38: Q3.1 (G); also elsewhere on the board

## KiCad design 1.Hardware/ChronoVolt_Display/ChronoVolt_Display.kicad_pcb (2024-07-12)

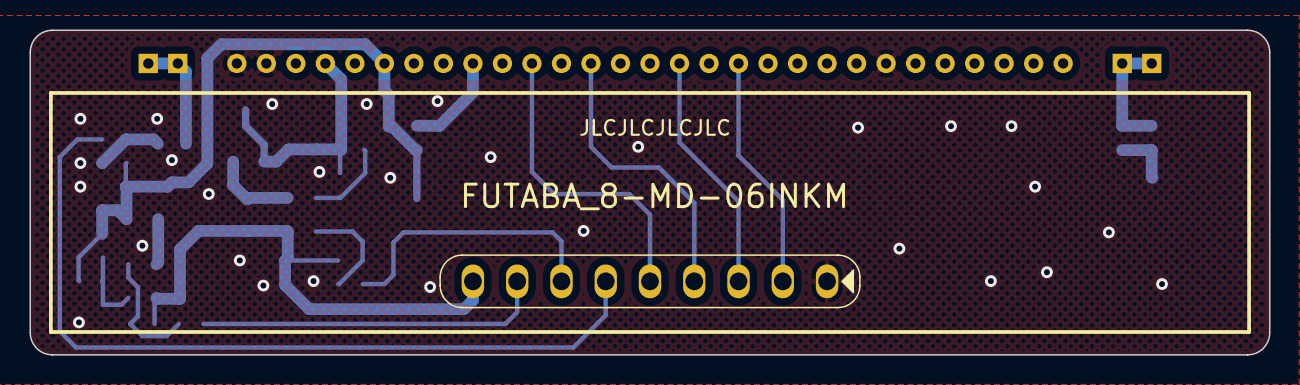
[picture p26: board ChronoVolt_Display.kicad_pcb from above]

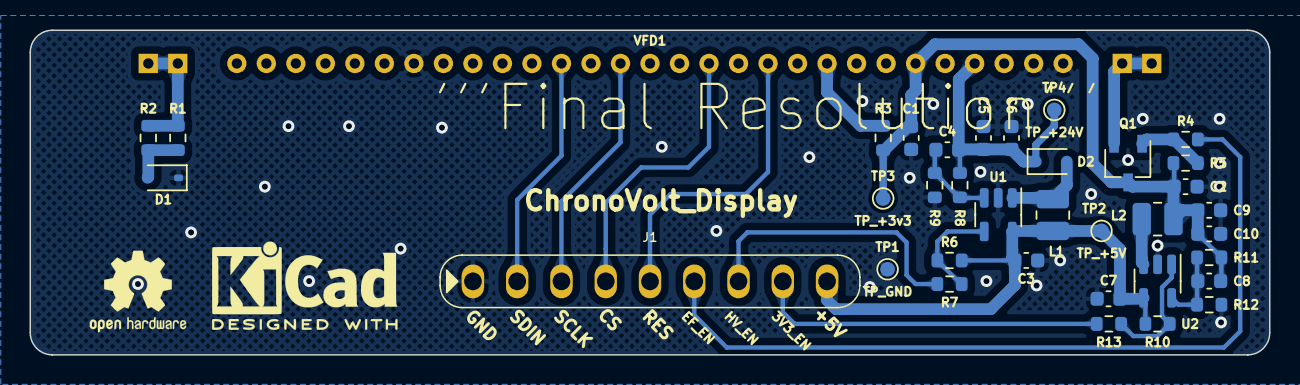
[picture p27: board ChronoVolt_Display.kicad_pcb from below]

Board: 2 copper layers, 84.0 x 22.0 mm, 36 parts (34 on the bottom side), 22 nets.

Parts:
C1: 0.1uF; C_0603_1608Metric
C2: 47uF; C_0603_1608Metric
C3, C7, C9, C10: 22μF; C_0603_1608Metric
C4: 22pF/50V; C_0603_1608Metric
C5: 0.1μF/50V; C_0603_1608Metric
C6: 4.7μF/50V; C_0603_1608Metric
C8: 22pF; C_0603_1608Metric
D1, D2: 1N5819WS; D_SOD-323
J1: Conn_01x09_Pin; Con_Pin_1x09_3mm
L1: 10uH; L_1008_2520Metric
L2: 2.2μH; L_1008_2520Metric
Q1: CJ2301; TSOT-23
R1, R2: 3R; R_0603_1608Metric
R3: 39K; R_0603_1608Metric
R4: 180R; R_0603_1608Metric
R5, R6, R7, R10, R13: 10K; R_0603_1608Metric
R8: 300K; R_0603_1608Metric
R9: 16K; R_0603_1608Metric
R11: 100K; R_0603_1608Metric
R12: 22K; R_0603_1608Metric
TP1: TP_GND; TestPoint_Pad_D1.0mm
TP2: TP_+5V; TestPoint_Pad_D1.0mm
TP3: TP_+3v3; TestPoint_Pad_D1.0mm
TP4: TP_+24V; TestPoint_Pad_D1.0mm
U1: SGM6601YTN5G/TR; TSOT-23-5
U2: SY8089AAAC; SOT-23-5
VFD1: Futaba_8-MD-06INKM; FUTABA_8-MD-06INKM

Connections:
3V3_EN: J1.8, R13.2
+3V3: C1.1, C2.1, C8.1, C9.1, C10.1, L2.2, Q1.3 (D), R3.2, R5.1, R11.1, TP3.1, VFD1.27 (VDD)
+5V: C3.1, C7.1, J1.9, L1.1, R6.1, R10.1, TP2.1, U1.5 (VIN), U2.4 (IN)
+24V: C4.1, C5.1, C6.1, D2.1 (K), R8.1, TP4.1, VFD1.29 (VH)
/VFD_8-MD-06INKM/F+: Q1.2 (S), VFD1.34 (F+), VFD1.35 (F+)
/VFD_8-MD-06INKM/F-: R1.1, R2.1, VFD1.1 (F-), VFD1.2 (F-)
EF_EN: J1.6, R4.2
GND: C1.2, C2.2, C3.2, C5.2, C6.2, C7.2, C9.2, C10.2, D1.1 (K), J1.1, R9.2, R12.2, TP1.1, U1.2 (GND), U2.2 (GND), VFD1.10 (TSB), VFD1.31 (PGND), VFD1.32 (LGND)
HV_EN: J1.7, R7.2
unnamed: D1.2 (A), R1.2, R2.2
unnamed: D2.2 (A), L1.2, U1.1 (SW)
unnamed: Q1.1 (G), R4.1, R5.2
unnamed: R6.2, R7.1, U1.4 (EN)
unnamed: C4.2, R8.2, R9.1, U1.3 (FB)
unnamed: R10.2, R13.1, U2.1 (EN)
unnamed: C8.2, R11.2, R12.1, U2.5 (FB)
unnamed: L2.1, U2.3 (LX)
unnamed: R3.1, VFD1.24 (OSC)
VFD_CS: J1.4, VFD1.20 (CS)
VFD_RES: J1.5, VFD1.22 (RES)
VFD_SCLK: J1.3, VFD1.17 (SCLK)
VFD_SDIN: J1.2, VFD1.15 (SDIN)

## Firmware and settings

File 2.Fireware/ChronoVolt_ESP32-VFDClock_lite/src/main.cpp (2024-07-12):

#include <Arduino.h>
#include <ArduinoJson.h>
#include <OneButton.h>
#include <Ticker.h>
#include <WiFi.h>
#include <WiFiUdp.h>
#include <NTPClient.h> // Include NTPClient library
#include <TimeLib.h>   // Include Arduino time library
#include "time.h"      // 为了使用tm结构体
#include "FutabaVFD.h"
#include <pitches.h>     //音调库
#include <DIP-Arduino.h> //DIP开关库
#include <I2C_BM8563.h>

// 函数声明
void wifi_connect();
// void vfd_rolldisplay();
void clock_ararm();
void get_randomTime();
void VFD_welcome();
void beep(int note, int duration);
void beep_music();
void set_rtc_time();
void get_rtc_time();

#define LED_PIN 25

#define Buzzer_Pin 14

int melody[] = {
    NOTE_E5, NOTE_D5, NOTE_FS4, NOTE_GS4,
    NOTE_CS5, NOTE_B4, NOTE_D4, NOTE_E4,
    NOTE_B4, NOTE_A4, NOTE_CS4, NOTE_E4,
    NOTE_A4};

int durations[] = {
    8, 8, 4, 4,
    8, 8, 4, 4,
    8, 8, 4, 4,
    2};

I2C_BM8563 rtc(I2C_BM8563_DEFAULT_ADDRESS, Wire);

const char *ntpServer = "ntp3.aliyun.com";

const char *ssid = "XXXXXX";
const char *password = "XXXXXXXX";

// 定义网络连接标志，联网为1，离线为0
int NET_FLAG = 0;

// WIFI尝试连接时间，减少以测试离线模式，单位(秒)
#define WIFI_RETRY_COUNT 30

unsigned long previousMillis = 0;
unsigned long interval = 30000;

// 时间相关定义
int timeHours, timeMinute, timeSecond, timeMonth, timeMonthDay, timeYear;
String timeWeekDay, timeMonthName, timeDate, timeMonth0, timeMonthDay0;
String weekArray[] = {"Sun", "Mon", "Tues", "Wed", "Thur", "Fri", "Sat"};
// Week Days
String weekDays[7] = {"Sunday", "Monday", "Tuesday", "Wednesday", "Thursday", "Friday", "Saturday"};
// Month names
String months[12] = {"January", "February", "March", "April", "May", "June", "July", "August", "September", "October", "November", "December"};

// 格式化时间变量
String format_time = "00:00:00";
char format_time0[100];
String format_data = "3333/33/33";
char format_data0[100];

String randNumber;
int a = 25;
int b = 61;
int c = 61;

// 按钮设置
OneButton button1(15, true);
OneButton button2(16, true);
OneButton button3(17, true);

// DIP开关设置
uint8_t dipSwitchPins[] = {26, 27}; // 定义DIP开关引脚
DIPSwitch dipSwitch(dipSwitchPins, 2);

void setup()
{
  Serial.begin(115200);

  // 配置WS2812B PIN
  pinMode(LED_PIN, OUTPUT);
  digitalWrite(LED_PIN, LOW);

  // 配置蜂鸣器引脚
  pinMode(Buzzer_Pin, OUTPUT);

  // VFD 初始化
  pinMode(clk, OUTPUT);
  pinMode(din, OUTPUT);
  pinMode(cs, OUTPUT);
  pinMode(Reset, OUTPUT);
  digitalWrite(Reset, LOW);
  delayMicroseconds(5);
  digitalWrite(Reset, HIGH);
  VFD_init();

  // Init I2C
  Wire.begin();

  // Init RTC
  rtc.begin();

  // 连接wifi
  S1201_WriteStr(0, "WIFI ...");
  wifi_connect();
  if (WiFi.status() == WL_CONNECTED)
  {
    S1201_WriteStr(0, " ONLINE!");
    NET_FLAG = 1;
  }
  else
  {
    S1201_WriteStr(0, "OFFLINE!");
    NET_FLAG = 0;
  }
  delay(2000);

  switch (NET_FLAG)
  {
  case 0:              // 离线模式
    WiFi.disconnect(); // 停止连接WIFI
    break;
  case 1: // 在线模式
    // Set ntp time to local
    configTime(8 * 3600, 0, ntpServer);
    set_rtc_time();
    WiFi.disconnect(); // 停止连接WIFI,以降低功耗
    break;

  default:
    break;
  }

  // VFD欢迎动画
  VFD_welcome();

  Serial.println("Initialized");
}

void loop()
{
  unsigned long currentMillis = millis();
  // Serial.println(dipSwitch.getState()); // 读取并打印DIP开关值
  switch (dipSwitch.getState())
  {
  case 0:
    // get_NTPTime();               // 获取NTP时间
    get_rtc_time();                  // 获取本地RTC时间
    S1201_WriteStr(0, format_time0); // 显示当前时间
    get_randomTime();                // 随机时间
    clock_ararm();                   // 闹钟
    break;
  case 1:
    S1201_WriteStr(0, "-Attack-"); // 显示当前时间
    break;
  case 2:
    S1201_WriteStr(0, " -MUSIC-"); // 显示当前时间
    beep_music();
    break;
  case 3:
    S1201_WriteStr(0, " --RTC--"); // 显示当前时间
    get_rtc_time();
    break;
  default:
    break;
  }

  delay(1000);
}

// VFD显示欢迎动画
void VFD_welcome()
{
  //S1201_WriteStr(0, "--INIT--");
  Charloop1("--INIT--");
  delay(3000);
  // vfd_rolldisplay();

  S1201_clear(); // 清屏
  VFD_bright(0);
  S1201_WriteStr(0, "VFDclock");
  VFD_FadeIn(10); // VFD淡入效果
  delay(2000);
  S1201_WriteStr(0, "FinalRun");
  delay(2000);
  VFD_FadeOut(10); // VFD淡出效果
  delay(1000);
  VFD_bright(255);
  VFD_cmd(0xE9); // 全亮
  delay(1000);
}

// 随机时刻
void get_randomTime()
{
  if (format_time == "08:10:00")
  { // 每24小时进行一次随机
    a = random(0, 24);
    b = random(0, 60);
    c = random(0, 60);
  }
  String randomTime = String(a) + ":" + String(b) + ":" + String(c); // 组合随机时间
  // Serial.print("Random Time: ");
  // Serial.println(randomTime); // 打印输出随机时间

  if (timeHours == a && timeMinute == b && timeSecond == c) // 生成的随机时间与当前时间进行比对
  {
    randNumber = String(random(0, 10000000));                   // 生成随机数
    char *randNumber0 = const_cast<char *>(randNumber.c_str()); // 将随机数由String转换为char*类型
    for (int i = 0; i <= 3; i++)                                // 闪烁以加强提醒
    {
      S1201_clear(); // 清屏
      delay(300);
      S1201_WriteStr(1, "Random!!"); // 提醒进入随机时刻！！！
      delay(800);
    }
    S1201_clear();                  // 清屏
    S1201_WriteStr(0, randNumber0); // 显示随机数
    delay(random(3000, 10000));     // 显示随机数保持随机时间
  }
}

// 闹钟提醒
void clock_ararm()
{
  // 下班提醒
  if (format_time == "16:30:00")
  {
    for (int i = 0; i <= 3; i++) // 闪烁以加强提醒
    {
      S1201_clear(); // 清屏
      delay(200);
      S1201_WriteStr(0, "Go Home");
      delay(1000);
    }
    S1201_WriteStr(0, "Go Home");
    delay(3000);
  }
  // 每1min提醒当前日期
  if (timeSecond == 0)
  {
    // char *timeDate0 = const_cast<char *>(timeDate.c_str());
    S1201_WriteStr(0, format_data0);
    delay(2000);
  }
  // 每30s提醒周几
  if (timeSecond == 30)
  {
    char *timeWeekDay0 = const_cast<char *>(timeWeekDay.c_str());
    S1201_clear(); // 清屏
    S1201_WriteStr(2, timeWeekDay0);
    delay(2000);
  }
  // 每30min提醒喝水
  if (timeMinute == 30)
  {

    for (int i = 0; i <= 3; i++) // 闪烁以加强提醒
    {
      S1201_clear(); // 清屏
      delay(300);
      S1201_WriteStr(1, "Drink!");
      delay(800);
      S1201_clear(); // 清屏
      S1201_WriteStr(1, "Water!");
      delay(800);
    }
    S1201_WriteStr(0, "Drink!!!");
    delay(3000);
  }
}

// 通过普通方式连接WiFi，需定义SSID、PASSWORD
void wifi_connect()
{
  WiFi.mode(WIFI_STA);                // 设置Wifi工作模式为STA,默认为AP+STA模式
  WiFi.begin(ssid, password);         // 通过wifi名和密码连接到Wifi
  Serial.print("\r\nConnecting to "); // 串口监视器输出网络连接信息
  Serial.print(ssid);
  Serial.println(" ..."); // 显示设备正在尝试WiFi连接

  int i = 0; // 用来判定连接是否超时的累加量
             // 这里的循环用来判断是否连接成功的。连接过程中每隔500毫秒会检查一次是否连接成功，，并打一个点表示正在连接中
  // 连接成功后会给出提示，但是若60秒后还是没有连接上，则会提示超时
  while (WiFi.status() != WL_CONNECTED)
  {
    i++;
    delay(500);
    Serial.print(".");
    if (i > WIFI_RETRY_COUNT * 2)
    { // 如果还是连接不上，就判定为连接超时
      Serial.println("Connection timeout!");
      S1201_WriteStr(0, "TIMEOUT!");
      // Serial.println("Restart after 3 seconds!!!");
      delay(3000);
      WiFi.disconnect(); // 停止连接WIFI
      // ESP.restart();
      break; // 连接超时，进入离线模式
    }
  }

  if (WiFi.status() == WL_CONNECTED)
  {
    Serial.println("");                // WiFi连接成功后
    Serial.println("WiFi connected!"); // 将通过串口监视器输出"连接成功"信息。
    Serial.print("IP address: ");      // 同时还将输出IP地址。这一功能是通过调用
    Serial.println(WiFi.localIP());    // WiFi.localIP()函数来实现的。该函数的返回值即IP地址。
  }
  else
  {
    Serial.println("Wifi connection failed, please try again!");
    Serial.println("Activate offline mode");
  }
}

// BEEP函数，(音调，音长)
void beep(int note, int duration)
{
  tone(Buzzer_Pin, note, duration);
  delay(duration);
}

// BEEP MUSIC函数
void beep_music()
{
  int size = sizeof(durations) / sizeof(int);

  for (int note = 0; note < size; note++)
  {
    // to calculate the note duration, take one second divided by the note type.
    // e.g. quarter note = 1000 / 4, eighth note = 1000/8, etc.
    int duration = 1000 / durations[note];
    tone(Buzzer_Pin, melody[note], duration);

    // to distinguish the notes, set a minimum time between them.
    // the note's duration + 30% seems to work well:
    int pauseBetweenNotes = duration * 1.30;
    delay(pauseBetweenNotes);

    // stop the tone playing:
    noTone(Buzzer_Pin);
  }
}

// 从NTP对时到本地RTC
void set_rtc_time()
{
  // Get local time
  struct tm timeInfo;
  if (getLocalTime(&timeInfo))
  {
    // Set RTC time
    I2C_BM8563_TimeTypeDef timeStruct;
    timeStruct.hours = timeInfo.tm_hour;
    timeStruct.minutes = timeInfo.tm_min;
    timeStruct.seconds = timeInfo.tm_sec;
    rtc.setTime(&timeStruct);

    // Set RTC Date
    I2C_BM8563_DateTypeDef dateStruct;
    dateStruct.weekDay = timeInfo.tm_wday;
    dateStruct.month = timeInfo.tm_mon + 1;
    dateStruct.date = timeInfo.tm_mday;
    dateStruct.year = timeInfo.tm_year + 1900;
    rtc.setDate(&dateStruct);
  }
}

//  获取RTC时间
void get_rtc_time()
{
  I2C_BM8563_DateTypeDef dateStruct;
  I2C_BM8563_TimeTypeDef timeStruct;

  // Get RTC
  rtc.getDate(&dateStruct);
  rtc.getTime(&timeStruct);

  // Print RTC
  // Serial.printf("%04d/%02d/%02d %02d %02d:%02d:%02d\n",
  //             dateStruct.year,
  //             dateStruct.month,
  //             dateStruct.date,
  //             dateStruct.weekDay,
  //             timeStruct.hours,
  //             timeStruct.minutes,
  //            timeStruct.seconds);

  // Wait
  // delay(1000);

  timeHours = timeStruct.hours;
  // Serial.print("Hour: ");
  // Serial.println(timeHours);

  timeMinute = timeStruct.minutes;
  // Serial.print("Minutes: ");
  // Serial.println(timeMinute);

  timeSecond = timeStruct.seconds;
  // Serial.print("Seconds: ");
  // Serial.println(timeSecond);

  timeWeekDay = weekArray[dateStruct.weekDay];
  // Serial.print("Week Day: ");
  // Serial.println(timeWeekDay);
  sprintf(format_time0, "%02d:%02d:%02d", timeHours, timeMinute, timeSecond);
  // Serial.println(str_time0);
  format_time = String(format_time0);
  // Serial.print("Formatted Time: ");
  // Serial.println(format_time);

  // str_time = const_cast<char *>(format_time.c_str()); // 转换格式

  timeMonthDay = int(dateStruct.date);
  // Serial.print("Month day: ");
  // Serial.println(timeMonthDay);

  timeMonth = int(dateStruct.month);
  // Serial.print("Month: ");
  // Serial.println(timeMonth);

  timeMonthName = months[timeMonth - 1];
  // Serial.print("Month name: ");
  // Serial.println(timeMonthName);

  timeYear = dateStruct.year;
  // Serial.print("Year: ");
  // Serial.println(timeYear);

  // Print complete date:
  sprintf(format_data0, "%04d%02d%02d", timeYear, timeMonth, timeMonthDay);
  // Serial.println(format_data0);
  format_data = String(format_data0);
  //  Serial.print("Current date: ");
  //  Serial.println(format_data);
}

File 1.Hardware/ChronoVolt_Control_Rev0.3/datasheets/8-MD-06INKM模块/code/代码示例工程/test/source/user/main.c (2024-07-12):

/**
 * @file main.c
 * @author mangolu (mangolu81@gmail.com)
 * @brief N76E003系统入口函数
 * @version 1.0.0
 * @date 2019-04-19
 *
 * @copyright Copyright (c) 2019 mangolu All righits reserved
 *
 */

/** 所需头文件开始>>> */

#include "../n76e003/N76E003.h"
#include "../common/common.h"
#include "../user/config.h"
#include "../user/initial.h"
#include "../n76e003/gpio.h"
#include "../n76e003/clock.h"
// #include "uart.h"

#include "intrins.h"

#include "../devices/vfd_8md06inkm.h"

/** 所需头文件结束<<< */

/** 需要自行定义部分开始>>> */



uint8_t test[] = "VFD-TEST";
uint8_t time[] = "12:30:30";
uint8_t sec,min,hour;

void Delay1000ms();
/** 需要自行定义部分结束<<< */

void main(void) {

	Initial_System();	/** 初始化系统 */

	// VFD_8MD06INKM_Display_Char(0,'0');
	// VFD_8MD06INKM_Display_Char(1,'1');
	// VFD_8MD06INKM_Display_Char(2,'2');
	// VFD_8MD06INKM_Display_Char(3,'3');
	// VFD_8MD06INKM_Display_Char(4,'4');
	// VFD_8MD06INKM_Display_Char(5,'5');
	// VFD_8MD06INKM_Display_Char(6,'6');
	// VFD_8MD06INKM_Display_Char(7,'7');

	// VFD_8MD06INKM_Display_Char(0,'A');
	// VFD_8MD06INKM_Display_Char(1,'B');
	// VFD_8MD06INKM_Display_Char(2,'C');
	// VFD_8MD06INKM_Display_Char(3,'D');
	// VFD_8MD06INKM_Display_Char(4,'E');
	// VFD_8MD06INKM_Display_Char(5,'F');
	// VFD_8MD06INKM_Display_Char(6,'G');
	// VFD_8MD06INKM_Display_Char(7,'H');

	// VFD_8MD06INKM_Display_String(0,test);
	// VFD_8MD06INKM_Display_String(0,time);
	PT6312_CS_L();
	VFD_8MD06INKM_Send(0xE9);	/** 全亮 */
	PT6312_CS_H();
	Delay1000ms();
	Delay1000ms();
	PT6312_CS_L();
	VFD_8MD06INKM_Send(0xEA);	/** 全灭 */
	PT6312_CS_H();
	Delay1000ms();
	PT6312_CS_L();
	VFD_8MD06INKM_Send(0xE9);	/** 全亮 */
	PT6312_CS_H();
	Delay1000ms();
	Delay1000ms();
	PT6312_CS_L();
	VFD_8MD06INKM_Send(0xEA);	/** 全灭 */
	PT6312_CS_H();
	Delay1000ms();
	PT6312_CS_L();
	VFD_8MD06INKM_Send(0xE9);	/** 全亮 */
	PT6312_CS_H();
	Delay1000ms();
	Delay1000ms();
	PT6312_CS_L();
	VFD_8MD06INKM_Send(0xEA);	/** 全灭 */
	PT6312_CS_H();
	Delay1000ms();
	PT6312_CS_L();
	VFD_8MD06INKM_Send(0xE8);	/** 正常操作 */
	PT6312_CS_H();
	Delay1000ms();
	VFD_8MD06INKM_Display_String(0,test);
	Delay1000ms();
	Delay1000ms();
	Delay1000ms();
	VFD_8MD06INKM_Display_String(0,time);
	Delay1000ms();
	Delay1000ms();
	Delay1000ms();

	while(1) {
		time[0] = hour / 10 + 0x30;
		time[1] = hour % 10 + 0x30;
		time[3] = min / 10 + 0x30;
		time[4] = min % 10 + 0x30;
		time[6] = sec / 10 + 0x30;
		time[7] = sec % 10 + 0x30;
		VFD_8MD06INKM_Display_String(0,time);
		Delay1000ms();
		sec += 1;
		if(sec == 60) {
			sec = 0;
			min += 1;
			if(min == 60) {
				min = 0;
				hour += 1;
				if(hour == 24) {
					hour = 0;
				}
			}
		}

		

	}
}


void Delay1000ms()		//@16MHz
{
	unsigned char i, j, k;

	i = 61;
	j = 204;
	k = 243;
	do
	{
		do
		{
			while (--k);
		} while (--j);
	} while (--i);
}
